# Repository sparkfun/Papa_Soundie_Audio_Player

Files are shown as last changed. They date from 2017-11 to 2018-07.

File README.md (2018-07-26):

SparkFun Papa Soundie Audio Player
========================================

Papa Soundie Audio Player

[*Papa Soundie Audio Player (14554)*](https://www.sparkfun.com/products/14554)

The SparkFun Papa Soundie is an audio playback device breaking out VS1000D audio codec IC allowing this little board the ability to decode OGG Vorbis and WAV type files. With an SD card for sound storage and a built-in ATmega328P programmed with Arduino you’ll be adding custom sound effects to your project with less hardware and in a familiar programming environment.

The Papa Soundie is the upgraded version of the Little Soundie with similar areas that allow you, the user, to interact with the board but with more customizable options. The top section of this board contains the Arduino Controls. We’ve broken out 2 analog input pins and 7 digital pins, which includes three PWM pins, SPI and I2C communication pins on the ATMEGA328P to easily control audio playback using sensors and other input.

Up to 32 files can be triggered to play from a micro SD card allowing for more storage space than that allowed on the Little Soundie. To play the audio stored in the SD card, plug in a powered speaker to the 3.5mm jack, upload an Arduino sketch the uses the Papa Soundie library, and start jammin'.

_Note: Speakers are required for the Papa Soundie, not headphones. Headphones won’t break anything but you won’t get any sound either._

Repository Contents
-------------------

* **/Documentation** - Data sheets, additional product information
* **/Enclosure** - Enclosure files 
* **/Firmware** - Example code 
* **/Hardware** - Eagle design files (.brd, .sch)
* **/Libraries** - Libraries for use with the Papa Soundie
* **/Production** - Production panel files (.brd)
* **/Software** - Related software for the Papa Soundie

Documentation
--------------
* **[Library](https://github.com/sparkfun/Papa_Soundie_Audio_Player)** - <C> library for the Papa Soundie.
* **[Hookup Guide](https://learn.sparkfun.com/tutorials/papa-soundie-audio-player-hookup-guide)** - Basic hookup guide for the Papa Soundie.
* **[SparkFun Fritzing repo](https://github.com/sparkfun/Fritzing_Parts)** - Fritzing diagrams for SparkFun products.
* **[SparkFun 3D Model repo](https://github.com/sparkfun/3D_Models)** - 3D models of SparkFun products. 
* **[SparkFun Graphical Datasheets](https://github.com/sparkfun/Graphical_Datasheets)** -Graphical Datasheets for various SparkFun products.

License Information
-------------------

This product is _**open source**_! 

Please review the LICENSE.md file for license information. 

If you have any questions or concerns on licensing, please contact techsupport@sparkfun.com.

Distributed as-is; no warranty is given.

- Your friends at SparkFun.

_<COLLABORATION CREDIT>_

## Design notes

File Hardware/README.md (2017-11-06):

SparkFun <PRODUCT NAME> Design Files
=====================================

The .sch and .brd files hare are Eagle CAD schematic and PCB design files from SparkFun Electronics.
A freeware version of Eagle can be found [here](http://www.cadsoftusa.com/download-eagle/freeware/).

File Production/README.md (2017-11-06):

SparkFun <PRODUCT NAME> Production Files
=========================================

These are the production files SparkFun uses for printing PCBs.

License Information
-------------------
This product is open source! 

The hardware is released under [Creative Commons ShareAlike 4.0 International](https://creativecommons.org/licenses/by-sa/4.0/).

Please use, reuse, and modify these files as you see fit. Please maintain attribution to SparkFun Electronics and release anything derivative under the same license.

Distributed as-is; no warranty is given.

- Your friends at SparkFun.

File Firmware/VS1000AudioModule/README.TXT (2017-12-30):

VS1000 Audio Module default firmware v0.72			20150720
-------------------------------------------------------------

Quickstart with VSIDE:
- Decompress the source code into your Solutions directory
- Start VSIDE and open VS1000AudioModule.solution
- Build all, and spiall.spi is created in the solution directory
  it is also copied to eeprom.img for easier programming
- Then program the module with the Prommer/Flasher utility
	"VS1000 SPI Flasher (24-bit) prepared image"
- If you don't have this version, you need to add the following entry to
  VSIDE\bin\prommer.index:

[vs1000_spi_flash_24bit_preparedimage]
Name                           = "VS1000 SPI Flasher (24-bit) prepared image"
TargetPlatform                 = "VS1000"
Description                    = "This VS1000 prommer can program SPI Flash memory chips with 24-bit address space. Communication is handled via UART cable. Image file has been prepared already by post-build step."
ImageName                      = "eeprom.img"
UseVs3Emu                      = "1"
PrommerBinary                  = "uniprom1k24.bin"
PrommerMemDesc                 = "prommer24.mem"

- One of the projects also create SDUPDATE.PRG for updates through SD card.
- Change settings from system.h (UART/GPIO, with or without WAV etc.)

Quickstart with Makefile:
- "make" (or "gmake") will compile and link the default firmware
- "make program" will program the default firmware to SPI FLASH
   if the FLASH already has a program, you must power on with SPI boot disabled

You can also use spi.bat to program the firmware:
> make spiall.spi prommer24.bin
> vs3emu -chip vs1000 -s 115200 -p 1 -l prommer24.bin -c run.cmd

Also see gpio-controlled player version.

Using SDUPDATE.PRG:
- SDUPDATE.PRG is a normal program, so it can do anything. The default
  SDUPDATE.PRG in the 0.4 version can update both the boot image
  (FIRMWARE.RAW) and the FAT disk content (CONTENT.RAW), depending on
  what files it finds on the SD card.
- Copy spiall.spi to FIRMWARE.RAW to update the firmware
- You can create CONTENT.RAW with for example the VS1000 image creator.
  Select SPI FLASH, no boot code, and set the Force FAT start to sector 0,
  so the resulting image will contain only the FAT.
- The SDUPDATE.PRG mechanism also exists in the 0.3 version,
  so you can update to 0.4 using uSD card.

Changes
=======
v0.72
- 20150720 with USE_POWERBUTTON, now requires the power button to be active
	for 0.2 sec before shutting down. (The 2FIN2 batch produces a
	pulse to PWRBTN when the uSD regulator is enabled.)

v0.70
- 20150113 The module datasheet updated.
- 20150107 USE_INFO includes 'i'nfo and 'I'nfo command to get the
	play length in seconds of a file without playing it. The same
	commands can be used to determine if a file exists.
- 20141117 USE_POWERBUTTON is now the default. You can turn off the module
	with a long press of the power button and turn the unit back on
	using the same button.
- 20141117 GAPLESS option added - selecting it from system.h will play files
	as back-to-back as possible. Only one-byte file number is printed when
	starting play and a single 'd' is sent when play ends (if UART mode).
- 20141117 A full version string with extra qualifiers such as
	-uart, -gpio, -queue, -filemode, -gapless is printed after startup.
- 20141115 Detects SPI FLASH size using the REMS sequence, so the size of
	the FLASH does not need to be correct when compiling the firmware.
	(If you want to reserve space for your own use, increase the
	 RESERVED_BLOCKS definition and use sectors from 64 upwards.)
- 20141113 Separated SD player and SD mass storage code. This frees up
	space so that more features can be used. The drawback is that uSD
	communication is reinitialized when switching between modes.
- 20141111 Fixed USE_MULTIPLE_BLOCK_WRITE in sdplayer.c . With it you
	can get around 500kB per second write speed to a modern uSD card.
	Note: This is not a default setting. You need to disable some other
	feature to fit it in (#undef USE_WAV in sdplayer.c or
	comment out //#define USE_WAV in system.h).
v0.65
- 20141028 Fixed 'P'lay by name when you have mixed OGG and WAV files.
	(Also gives file not found now if the file does not exist.)
v0.63
- 20140624 Added special button functions to gpioctrl.c .
   - prioritized buttons to select songs 1-3
   - STOP button
   - volume up and down buttons
   - power button is supported through USE_POWERBUTTON
v0.62
- 20140613 Added USE_POWERBUTTON to enable turn off using the PB input.
v0.61
- 20130923 Queueing option added. Enable both USE_QUEUE and DISABLE_USB
   from system.h to use it. DISABLE_USB removes the USB functionality from
   sdplayer.c, so that the queueing code can fit.
   When USE_QUEUE is active, the firmware starts in file mode. While in
   file mode and not playing, you can add files to the queue with
   "QFILENAMEOGG\n". If the file was found, the response will be
   "add FILENAME\n" or "ful\n" if there is no space in the queue,
   otherwise "nof FILENAME\n" (not found).
   Each queued file is added to the end of the queue.
   You can start playing the queue with "p0\n".
   In the play mode 'C' (cancel) only ends the play of the current file
   and continues with the next file in the queue. The same applies to
   'p' (previous) and 'n' (next) commands.

v0.60
- 20130118 MicroWav can now be enabled with USB (new libdev1000 required,
   included under lib/ with this VSIDE release).
	microwav does not support fast forward
0.51
- 20120621 Option to delete SDUPDATE.PRG from the SD card (see sdupdate.c)
- 20120621 Added a beep after programming is complete and you should remove the card.
 
0.5
- 20111209 VSIDE Solution of the UART version
- 20111209 mass storage functions changed. usbmass.c no longer
	provides audio + mass storage because win2000 and win7
	had some trouble with this kind of  composite device.
- 20111209 sdupdate.c: added a beep after programming is finished
- 20111025 sdplayer.c: removed GPIO_CONTROL stuff,
	added PatchPlayCurrentFile and PatchDiskProtocolCommandDE,
	fixes to uSD handling, MyMassStorage cleaned up.
	   spiplayer.c: removed GPIO_CONTROL stuff

0.4
- 20110429 QUIET_CANCEL define added (inactive) in uartctrl.c:
	when cancelled from pause state, lower volume so that
	portion of the old song will not be played.
- 20101223 Separated GPIO_CONTROL into its own package
- 20101213 Created GPIO_CONTROL version
- 20101115 Exec() crashed if not a valid FAT filesystem in SPI FLASH. (fixed)

0.31 20101115
- Changes to source package only. Makefile did not pass the MMCSTART
  define correctly in Linux and Windows.

0.3 20101027
- Added SD playback with UART control. The software now consists of
  three parts:
  1) usbmass, which is executed after power-on and handles USB Mass Storage
     for SPI FLASH, and loads spiplayer or sdplayer depeding on the SD/MMC
     insertion switch.
  2) spiplayer, which plays SPI FLASH content, loads sdplayer if SD/MMC
     insertion switch is triggered, and loads usbmass (using watchdog reset)
     if USB attachment is detected.
  3) sdplayer, which plays from SD/MMC, and also handles USB Mass Storage,
     and loads spiplayer if SD/MMC insertion switch is triggered.

0.2 20101011
- First version, UART control and playback from SPI FLASH.

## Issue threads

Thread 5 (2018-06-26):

Error in attempt to add library to Arduino 1.8.5.

restorey, 2018-06-26:
I cannot add Papa_Soundie_Audio_Player Library to Arduino IDE. When I try I get an error.
"Specified folder/zip file does not contain a valid library"

Arduino: 1.8.5 (Windows 10), Board: "Arduino Due (Programming Port)"

I am at a loss as to why this error pops up except there must be something wrong with the file.

per1234, 2018-06-26:
It's only possible to install libraries from a .zip file when the library is in the root of the file but in this case the library is in a subfolder so you can't use that installation technique with the .zip file of the entire repository.

SparkFun has added a .zip file of the library itself to the repository that you can use to install the library via the "Add .ZIP Library" technique:

1. Download https://github.com/sparkfun/Papa_Soundie_Audio_Player/raw/master/Libraries/Arduino/src.zip
2. (In the Arduino IDE) Sketch > Include Library > Add .ZIP Library > select the downloaded file > Open

restorey, 2018-06-26:
per1234. Thank you for the quick response. Download is now functional.
The problem stemmed from a link in the SparkFun tutorial for the Papa_Soundie_audio_player_hookup_guide.

Closed 2018-06-26.

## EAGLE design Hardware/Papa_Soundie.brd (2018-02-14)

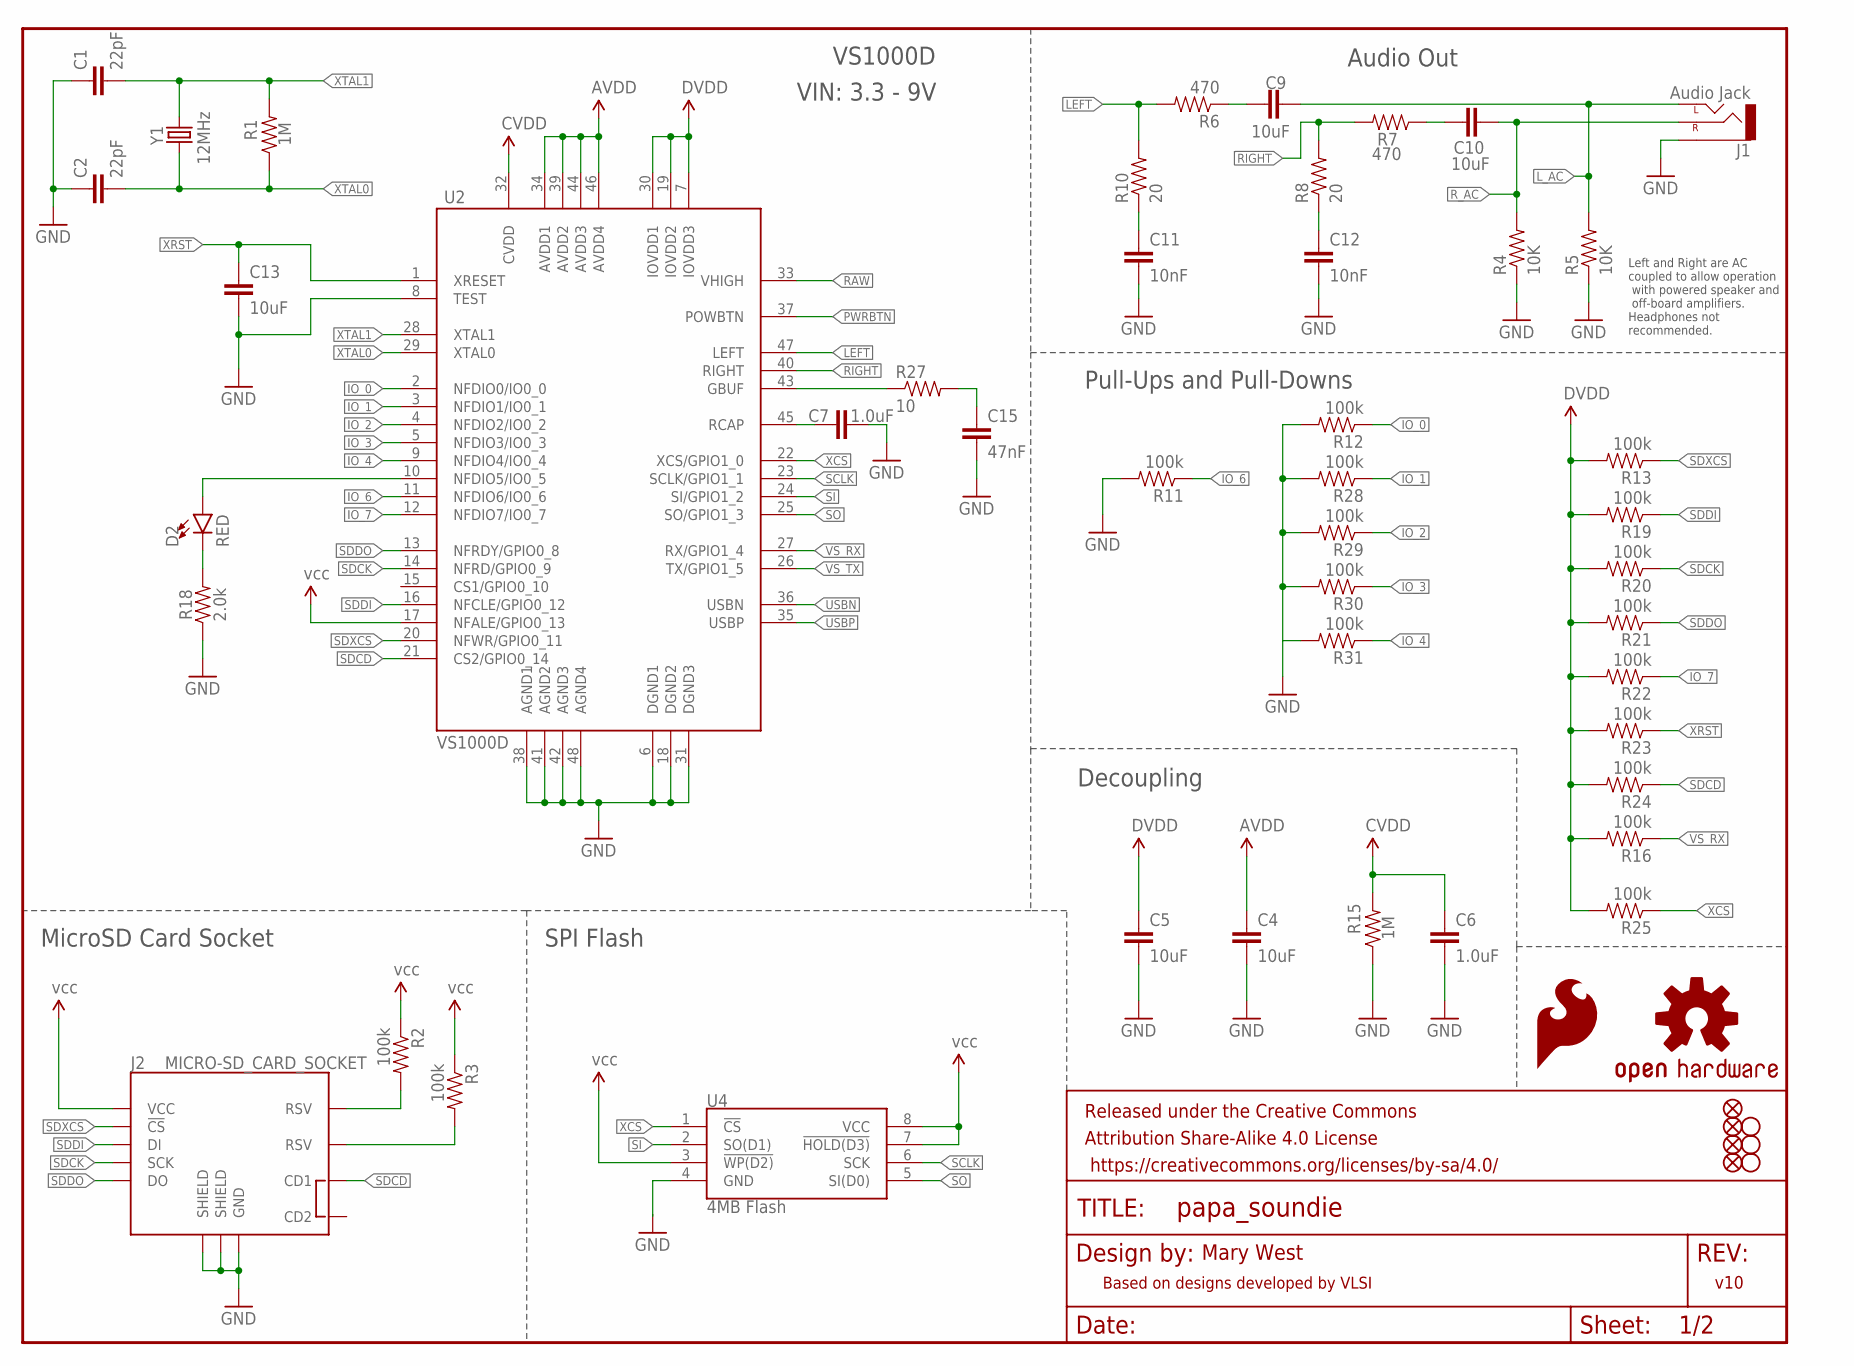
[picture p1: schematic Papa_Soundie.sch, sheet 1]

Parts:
C1, C2: 22pF; 0603-CAP
C4, C5: 10uF; 0603
C6, C7: 1.0uF; 0603-CAP
C9, C10, C13: 10uF; 0603-CAP
C11, C12: 10nF; 0603-CAP
C15: 47nF; 0603-CAP
D2: RED; LED-0603
FD1, FD2, FD3, FD4: FIDUCIALUFIDUCIAL; FIDUCIAL-MICRO
FRAME1: FRAME-LETTER; CREATIVE_COMMONS
H1, H2, H3: STAND-OFFTIGHT; STAND-OFF-TIGHT
J1: Audio Jack; AUDIO-JACK-3.5MM-SMD
J2: MICRO-SD_CARD_SOCKET; MICRO-SD-SOCKET
LOGO1: OSHW-LOGOL; OSHW-LOGO-L
LOGO2: SFE_LOGO_FLAME.2_INCH; SFE_LOGO_FLAME_.2
R1, R15: 1M; 0603-RES
R2, R3, R11, R12, R13, R16, R19, R20, R21, R22, R23, R24, R25, R28, R29, R30, R31: 100k; 0603-RES
R4, R5: 10K; 0603-RES
R6, R7: 470; 0603-RES
R8, R10: 20; 0603-RES
R18: 2.0k; 0603
R27: 10; 0603-RES
U2: VS1000D; LQFP-48
U4: 4MB Flash; SO08
Y1: 12MHz; CRYSTAL-SMD-5X3

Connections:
AVDD: C4.1, U2.34 (AVDD1), U2.39 (AVDD2), U2.44 (AVDD3), U2.46 (AVDD4)
CVDD: C6.1, R15.2, U2.32 (CVDD)
DVDD: C5.1, R13.2, R16.2, R19.2, R20.2, R21.2, R22.2, R23.2, R24.2, R25.2, U2.7 (IOVDD3), U2.19 (IOVDD2), U2.30 (IOVDD1)
GBUF: R27.1, U2.43 (GBUF)
GND: C1.1, C2.1, C4.2, C5.2, C6.2, C7.2, C11.2, C12.2, C13.2, C15.2, J1.SLEEVE, J2.GND, J2.GND1 (SHIELD), J2.GND3 (SHIELD), R4.1, R5.1, R11.2, R12.2, R15.1, R18.1, R28.2, R29.2, R30.2, R31.2, U2.6 (DGND1), U2.8 (TEST), U2.18 (DGND2), U2.31 (DGND3), U2.38 (AGND1), U2.41 (AGND2), U2.42 (AGND3), U2.48 (AGND4), U4.4 (GND); also elsewhere on the board
IO_0: R12.1, U2.2 (NFDIO0/IO0_0); also elsewhere on the board
IO_1: R28.1, U2.3 (NFDIO1/IO0_1); also elsewhere on the board
IO_2: R29.1, U2.4 (NFDIO2/IO0_2); also elsewhere on the board
IO_3: R30.1, U2.5 (NFDIO3/IO0_3); also elsewhere on the board
IO_4: R31.1, U2.9 (NFDIO4/IO0_4); also elsewhere on the board
IO_6: R11.1, U2.11 (NFDIO6/IO0_6)
IO_7: R22.1, U2.12 (NFDIO7/IO0_7)
LEFT: R6.2, R10.2, U2.47 (LEFT)
L_AC: C9.2, J1.TIP (LEFT), R5.2; also elsewhere on the board
unnamed: C15.1, R27.2
unnamed: C9.1, R6.1
unnamed: C11.1, R10.1
unnamed: C7.1, U2.45 (RCAP)
unnamed: J2.RSV1 (RSV), R2.2
unnamed: C10.1, R7.1
unnamed: J2.RSV2 (RSV), R3.2
unnamed: C12.1, R8.1
unnamed: D2.C, R18.2
unnamed: D2.A, U2.10 (NFDIO5/IO0_5)
PWRBTN: U2.37 (POWBTN); also elsewhere on the board
RAW: U2.33 (VHIGH); also elsewhere on the board
RIGHT: R7.2, R8.2, U2.40 (RIGHT)
R_AC: C10.2, J1.RING (RIGHT), R4.2; also elsewhere on the board
SCLK: U2.23 (SCLK/GPIO1_1), U4.6 (SCK)
SDCD: J2.CD1, R24.1, U2.21 (CS2/GPIO0_14)
SDCK: J2.SCLK (SCK), R20.1, U2.14 (NFRD/GPIO0_9)
SDDI: J2.DI, R19.1, U2.16 (NFCLE/GPIO0_12)
SDDO: J2.DO, R21.1, U2.13 (NFRDY/GPIO0_8)
SDXCS: J2.CS (!CS), R13.1, U2.20 (NFWR/GPIO0_11)
SI: U2.24 (SI/GPIO1_2), U4.2 (SO(D1))
SO: U2.25 (SO/GPIO1_3), U4.5 (SI(D0))
USBN: U2.36 (USBN); also elsewhere on the board
USBP: U2.35 (USBP); also elsewhere on the board
VCC: J2.VCC, R2.1, R3.1, U2.17 (NFALE/GPIO0_13), U4.3 (!WP(D2)), U4.7 (!HOLD(D3)), U4.8 (VCC); also elsewhere on the board
VS_RX: R16.1, U2.27 (RX/GPIO1_4); also elsewhere on the board
VS_TX: U2.26 (TX/GPIO1_5); also elsewhere on the board
XCS: R25.1, U2.22 (XCS/GPIO1_0), U4.1 (!CS)
XRST: C13.1, R23.1, U2.1 (XRESET)
XTAL0: C2.2, R1.1, U2.29 (XTAL0), Y1.1
XTAL1: C1.2, R1.2, U2.28 (XTAL1), Y1.3 (2)

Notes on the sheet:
Mary West
v10
Decoupling
Left and Right are AC coupled to allow operation with powered speaker and off-board amplifiers. Headphones not recommended.
Based on designs developed by VLSI
Audio Out
MicroSD Card Socket
Pull-Ups and Pull-Downs
SPI Flash
VS1000D
VIN: 3.3 - 9V

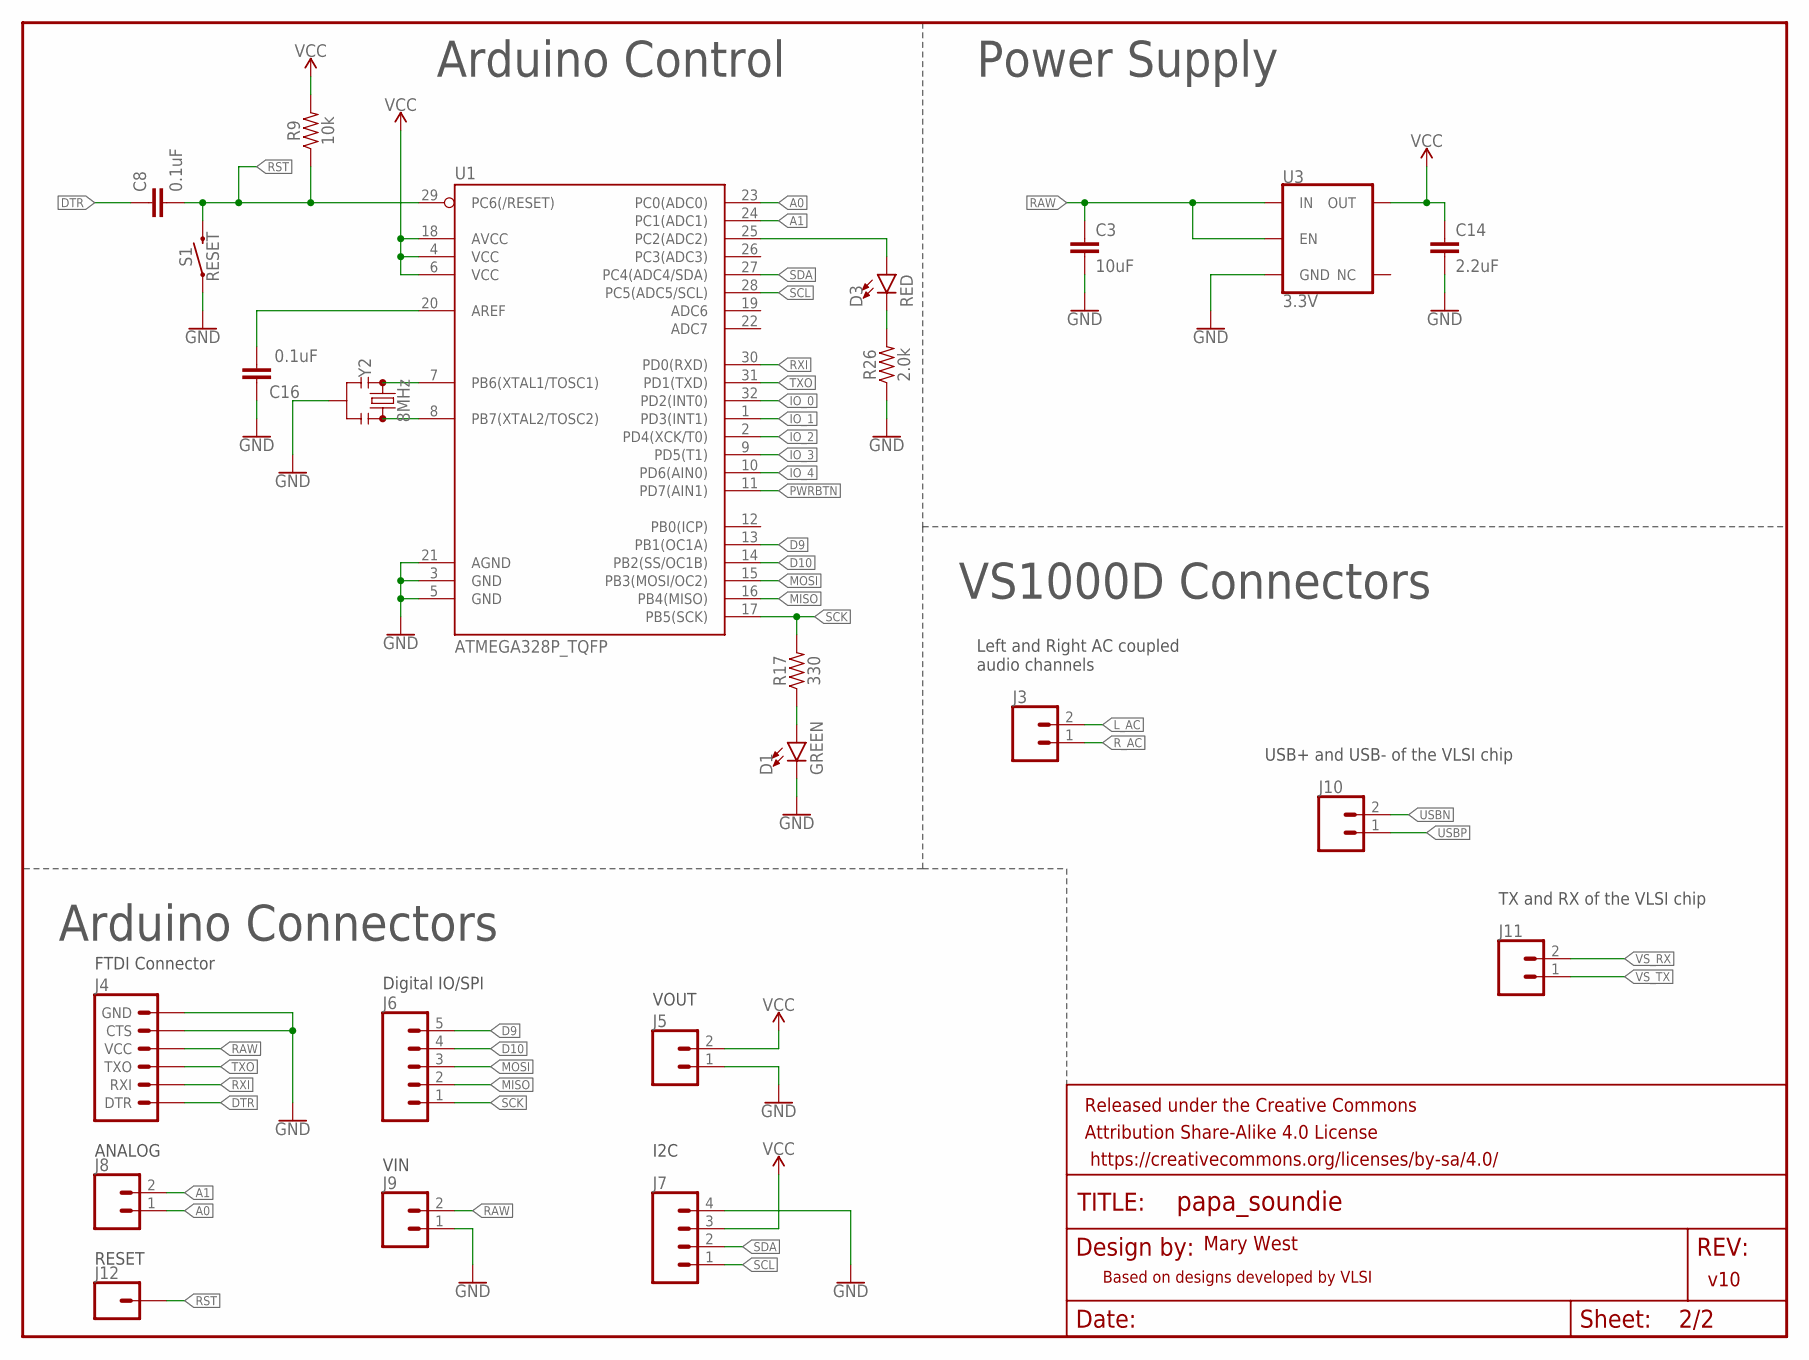
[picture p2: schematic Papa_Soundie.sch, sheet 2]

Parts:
C3: 10uF; 0603
C8, C16: 0.1uF; 0603
C14: 2.2uF; 0603
D1: GREEN; LED-0603
D3: RED; LED-0603
FRAME2: FRAME-LETTER; CREATIVE_COMMONS
J3, J5, J8, J9, J10, J11: CONN_02; 1X02
J4: 6_PIN_SERIAL_TARGETSILK; 6_PIN_SERIAL_TARGET_SIDE_W_SILK
J6: CONN_05; 1X05
J7: CONN_04; 1X04
J12: CONN_01; 1X01
R9: 10k; 0603
R17: 330; 0603
R26: 2.0k; 0603
S1: RESET; TACTILE_SWITCH_SMD_5.2MM
U1: ATMEGA328P_TQFP; TQFP32-08
U3: 3.3V; SOT23-5
Y2: 8MHz; RESONATOR-SMD-3.2X1.3

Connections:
A0: J8.1, U1.23 (PC0(ADC0))
A1: J8.2, U1.24 (PC1(ADC1))
D9: J6.5, U1.13 (PB1(OC1A))
D10: J6.4, U1.14 (PB2(SS/OC1B))
DTR: C8.1, J4.P$1 (DTR)
GND: C3.2, C14.2, C16.1, D1.C, J4.P$5 (CTS), J4.P$6 (GND), J5.1, J7.4, J9.1, R26.1, S1.1, U1.3 (GND), U1.5 (GND), U1.21 (AGND), U3.2 (GND), Y2.2; also elsewhere on the board
IO_0: U1.32 (PD2(INT0)); also elsewhere on the board
IO_1: U1.1 (PD3(INT1)); also elsewhere on the board
IO_2: U1.2 (PD4(XCK/T0)); also elsewhere on the board
IO_3: U1.9 (PD5(T1)); also elsewhere on the board
IO_4: U1.10 (PD6(AIN0)); also elsewhere on the board
L_AC: J3.2; also elsewhere on the board
MISO: J6.2, U1.16 (PB4(MISO))
MOSI: J6.3, U1.15 (PB3(MOSI/OC2))
unnamed: U1.7 (PB6(XTAL1/TOSC1)), Y2.1
unnamed: U1.8 (PB7(XTAL2/TOSC2)), Y2.3
unnamed: D3.A, U1.25 (PC2(ADC2))
unnamed: D3.C, R26.2
unnamed: C16.2, U1.20 (AREF)
unnamed: D1.A, R17.1
PWRBTN: U1.11 (PD7(AIN1)); also elsewhere on the board
RAW: C3.1, J4.P$4 (VCC), J9.2, U3.1 (IN), U3.3 (EN); also elsewhere on the board
RST: C8.2, J12.1, R9.1, S1.3 (2), U1.29 (PC6(/RESET))
RXI: J4.P$3 (RXI), U1.30 (PD0(RXD))
R_AC: J3.1; also elsewhere on the board
SCK: J6.1, R17.2, U1.17 (PB5(SCK))
SCL: J7.1, U1.28 (PC5(ADC5/SCL))
SDA: J7.2, U1.27 (PC4(ADC4/SDA))
TXO: J4.P$2 (TXO), U1.31 (PD1(TXD))
USBN: J10.2; also elsewhere on the board
USBP: J10.1; also elsewhere on the board
VCC: C14.1, J5.2, J7.3, R9.2, U1.4 (VCC), U1.6 (VCC), U1.18 (AVCC), U3.5 (OUT); also elsewhere on the board
VS_RX: J11.2; also elsewhere on the board
VS_TX: J11.1; also elsewhere on the board

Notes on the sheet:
Arduino Control
Mary West
v10
Power Supply
VS1000D Connectors
Arduino Connectors
Left and Right AC coupled audio channels
USB+ and USB- of the VLSI chip
TX and RX of the VLSI chip
VOUT
I2C
Digital IO/SPI
FTDI Connector
ANALOG
VIN
RESET
Based on designs developed by VLSI

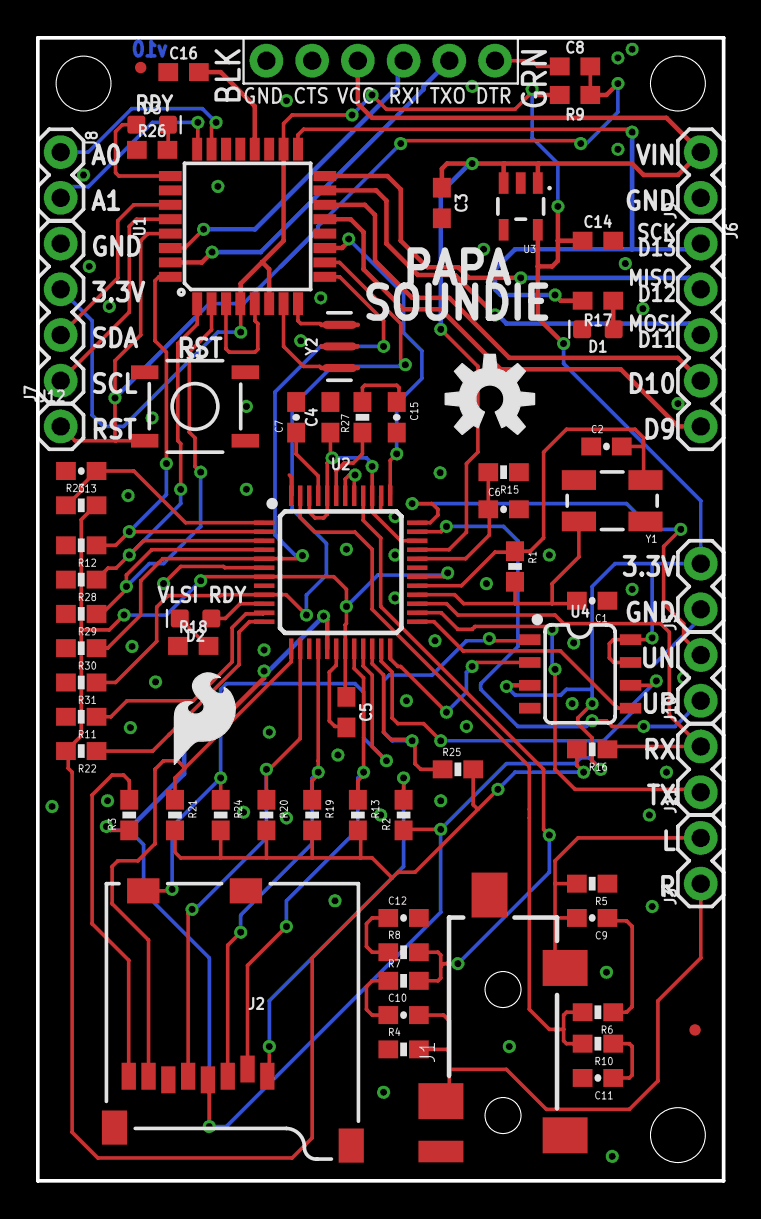
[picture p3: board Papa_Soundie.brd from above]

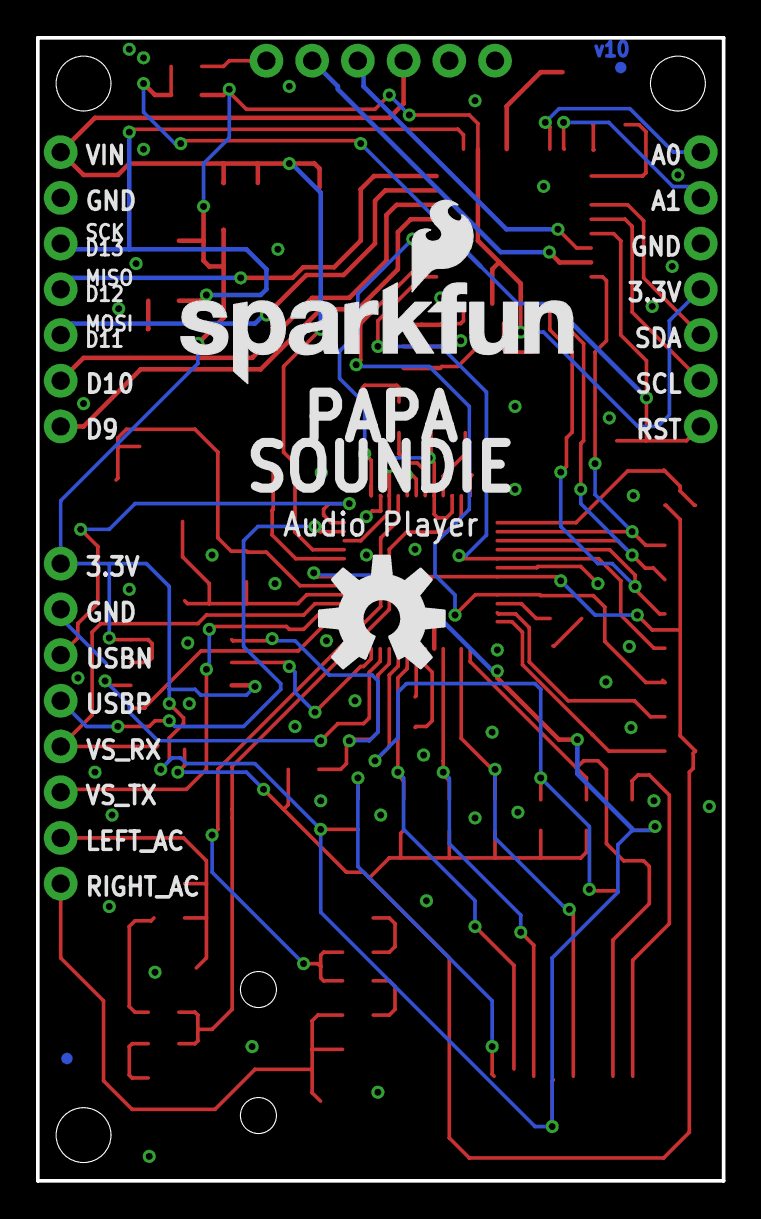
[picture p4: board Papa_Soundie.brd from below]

Board: 2 copper layers, 38.1 x 63.5 mm, 82 parts (4 on the bottom side), 64 nets.

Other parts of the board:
FRAME3: FRAME-LETTER; CREATIVE_COMMONS
LOGO3: OSHW-LOGOL; OSHW-LOGO-M
LOGO6: SFE_LOGO_NAME_FLAME.1_INCH; SFE_LOGO_NAME_FLAME_.2

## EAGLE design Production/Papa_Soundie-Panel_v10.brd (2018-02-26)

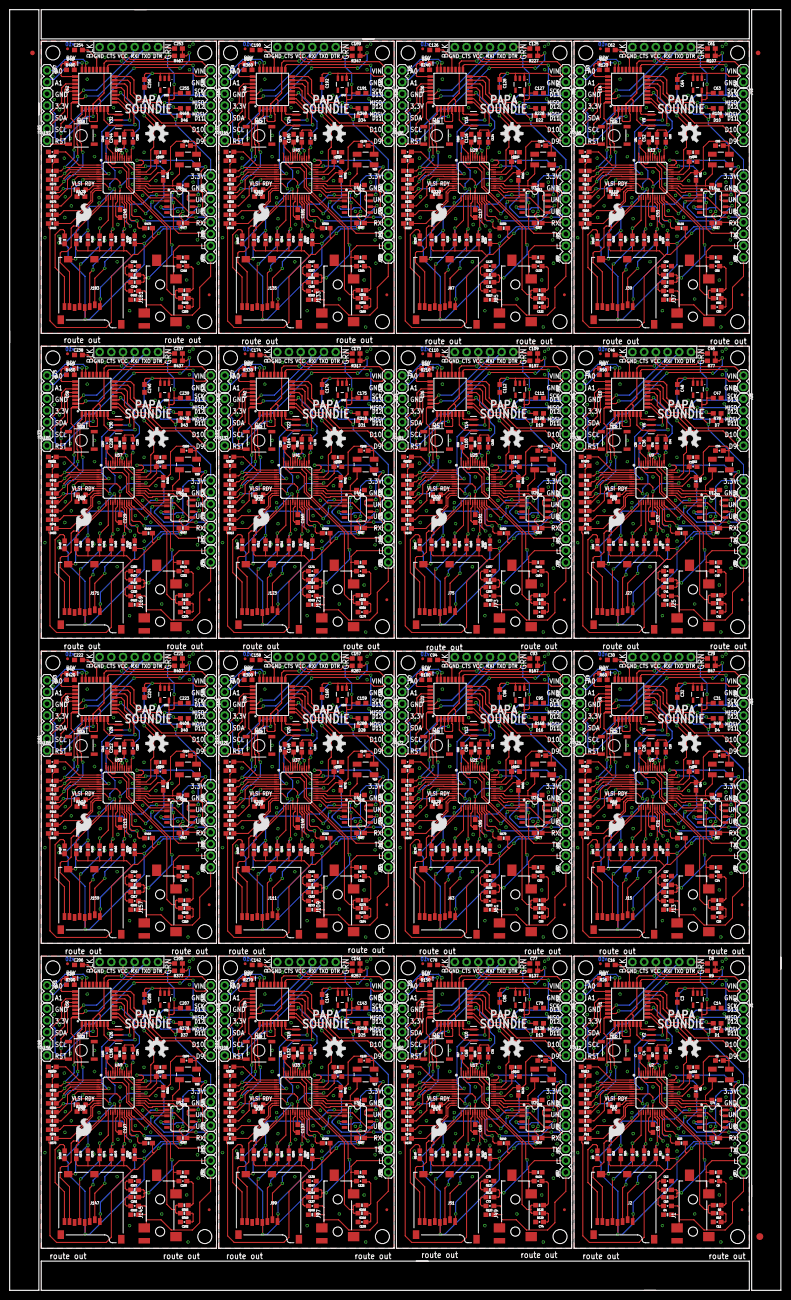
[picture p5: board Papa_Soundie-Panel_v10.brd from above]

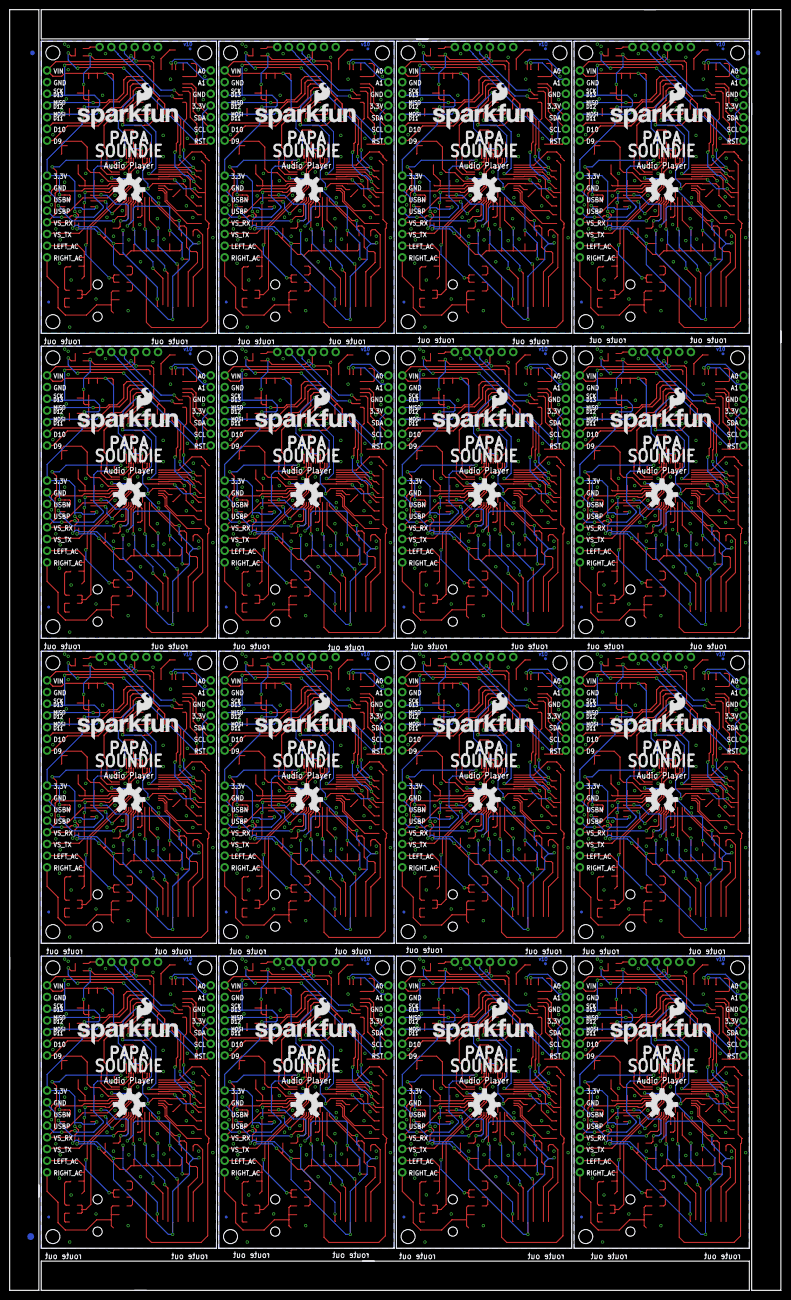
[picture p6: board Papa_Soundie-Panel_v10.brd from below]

Board: 2 copper layers, 167.6 x 278.4 mm, 1270 parts (67 on the bottom side), 1024 nets.

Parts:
C1, C2, C17, C18, C33, C34, C49, C50, C65, C66, C81, C82, C97, C98, C113, C114, C129, C130, C145, C146, C161, C162, C177, C178, C193, C194, C209, C210, C225, C226, C241, C242: 22pF; 0603-CAP
C3, C4, C5, C20, C21, C32, C36, C37, C48, C52, C53, C64, C68, C69, C80, C84, C85, C96, C100, C101, C112, C116, C117, C128, C132, C133, C144, C148, C149, C160, C164, C165, C176, C180, C181, C192, C196, C197, C208, C212, C213, C224, C228, C229, C240, C244, C245, C256: 10uF; 0603
C6, C7, C19, C22, C35, C38, C51, C54, C67, C70, C83, C86, C99, C102, C115, C118, C131, C134, C147, C150, C163, C166, C179, C182, C195, C198, C211, C214, C227, C230, C243, C246: 1.0uF; 0603-CAP
C8, C16, C29, C30, C45, C46, C61, C62, C77, C78, C93, C94, C109, C110, C125, C126, C141, C142, C157, C158, C173, C174, C189, C190, C205, C206, C221, C222, C237, C238, C253, C254: 0.1uF; 0603
C9, C10, C13, C23, C24, C25, C39, C40, C41, C55, C56, C57, C71, C72, C73, C87, C88, C89, C103, C104, C105, C119, C120, C121, C135, C136, C137, C151, C152, C153, C167, C168, C169, C183, C184, C185, C199, C200, C201, C215, C216, C217, C231, C232, C233, C247, C248, C249: 10uF; 0603-CAP
C11, C12, C26, C27, C42, C43, C58, C59, C74, C75, C90, C91, C106, C107, C122, C123, C138, C139, C154, C155, C170, C171, C186, C187, C202, C203, C218, C219, C234, C235, C250, C251: 10nF; 0603-CAP
C14, C31, C47, C63, C79, C95, C111, C127, C143, C159, C175, C191, C207, C223, C239, C255: 2.2uF; 0603
C15, C28, C44, C60, C76, C92, C108, C124, C140, C156, C172, C188, C204, C220, C236, C252: 47nF; 0603-CAP
D1, D4, D7, D10, D13, D16, D19, D22, D25, D28, D31, D34, D37, D40, D43, D46: GREEN; LED-0603
D2, D3, D5, D6, D8, D9, D11, D12, D14, D15, D17, D18, D20, D21, D23, D24, D26, D27, D29, D30, D32, D33, D35, D36, D38, D39, D41, D42, D44, D45, D47, D48: RED; LED-0603
E$1, E$2: FIDUCIAL-1.5X3
E$3, E$4, E$6, E$7: FIDUCIAL-1X2
FD1, FD2, FD3, FD4, FD5, FD6, FD7, FD8, FD9, FD10, FD11, FD12, FD13, FD14, FD15, FD16, FD17, FD18, FD19, FD20, FD21, FD22, FD23, FD24, FD25, FD26, FD27, FD28, FD29, FD30, FD31, FD32, FD33, FD34, FD35, FD36, FD37, FD38, FD39, FD40, FD41, FD42, FD43, FD44, FD45, FD46, FD47, FD48, FD49, FD50, FD51, FD52, FD53, FD54, FD55, FD56, FD57, FD58, FD59, FD60, FD61, FD62, FD63, FD64: FIDUCIALUFIDUCIAL; FIDUCIAL-MICRO
H1, H2, H3, H4, H5, H6, H7, H8, H9, H10, H11, H12, H13, H14, H15, H16, H17, H18, H19, H20, H21, H22, H23, H24, H25, H26, H27, H28, H29, H30, H31, H32, H33, H34, H35, H36, H37, H38, H39, H40, H41, H42, H43, H44, H45, H46, H47, H48: STAND-OFFTIGHT; STAND-OFF-TIGHT
J1, J13, J25, J37, J49, J61, J73, J85, J97, J109, J121, J133, J145, J157, J169, J181: Audio Jack; AUDIO-JACK-3.5MM-SMD
J2, J15, J27, J39, J51, J63, J75, J87, J99, J111, J123, J135, J147, J159, J171, J183: MICRO-SD_CARD_SOCKET; MICRO-SD-SOCKET
J3, J5, J8, J9, J10, J11, J18, J19, J20, J21, J22, J23, J30, J31, J32, J33, J34, J35, J42, J43, J44, J45, J46, J47, J54, J55, J56, J57, J58, J59, J66, J67, J68, J69, J70, J71, J78, J79, J80, J81, J82, J83, J90, J91, J92, J93, J94, J95, J102, J103, J104, J105, J106, J107, J114, J115, J116, J117, J118, J119, J126, J127, J128, J129, J130, J131, J138, J139, J140, J141, J142, J143, J150, J151, J152, J153, J154, J155, J162, J163, J164, J165, J166, J167, J174, J175, J176, J177, J178, J179, J186, J187, J188, J189, J190, J191: 1X02
J4, J14, J26, J38, J50, J62, J74, J86, J98, J110, J122, J134, J146, J158, J170, J182: 6_PIN_SERIAL_TARGET_SIDE_W_SILK
J6, J16, J28, J40, J52, J64, J76, J88, J100, J112, J124, J136, J148, J160, J172, J184: 1X05
J7, J17, J29, J41, J53, J65, J77, J89, J101, J113, J125, J137, J149, J161, J173, J185: 1X04
J12, J24, J36, J48, J60, J72, J84, J96, J108, J120, J132, J144, J156, J168, J180, J192: 1X01
LOGO1, LOGO4, LOGO9, LOGO13, LOGO17, LOGO21, LOGO25, LOGO29, LOGO33, LOGO37, LOGO41, LOGO45, LOGO49, LOGO53, LOGO57, LOGO61: OSHW-LOGOL; OSHW-LOGO-L
LOGO2, LOGO5, LOGO10, LOGO14, LOGO18, LOGO22, LOGO26, LOGO30, LOGO34, LOGO38, LOGO42, LOGO46, LOGO50, LOGO54, LOGO58, LOGO62: SFE_LOGO_FLAME.2_INCH; SFE_LOGO_FLAME_.2
LOGO3, LOGO8, LOGO12, LOGO16, LOGO20, LOGO24, LOGO28, LOGO32, LOGO36, LOGO40, LOGO44, LOGO48, LOGO52, LOGO56, LOGO60, LOGO64: OSHW-LOGOL; OSHW-LOGO-M
LOGO6, LOGO7, LOGO11, LOGO15, LOGO19, LOGO23, LOGO27, LOGO31, LOGO35, LOGO39, LOGO43, LOGO47, LOGO51, LOGO55, LOGO59, LOGO63: SFE_LOGO_NAME_FLAME.1_INCH; SFE_LOGO_NAME_FLAME_.2
R1, R14, R15, R32, R61, R62, R91, R92, R121, R122, R151, R152, R181, R182, R211, R212, R241, R242, R271, R272, R301, R302, R331, R332, R361, R362, R391, R392, R421, R422, R451, R452: 1M; 0603-RES
R2, R3, R11, R12, R13, R16, R19, R20, R21, R22, R23, R24, R25, R28, R29, R30, R31, R39, R40, R41, R42, R43, R44, R45, R49, R50, R51, R52, R53, R54, R55, R56, R57, R58, R69, R70, R71, R72, R73, R74, R75, R79, R80, R81, R82, R83, R84, R85, R86, R87, R88, R99, R100, R101, R102, R103, R104, R105, R109, R110, R111, R112, R113, R114, R115, R116, R117, R118, R129, R130, R131, R132, R133, R134, R135, R139, R140, R141, R142, R143, R144, R145, R146, R147, R148, R159, R160, R161, R162, R163, R164, R165, R169, R170, R171, R172, R173, R174, R175, R176, R177, R178, R189, R190, R191, R192, R193, R194, R195, R199, R200, R201, R202, R203, R204, R205, R206, R207, R208, R219, R220, R221, R222, R223, R224, R225, R229, R230, R231, R232, R233, R234, R235, R236, R237, R238, R249, R250, R251, R252, R253, R254, R255, R259, R260, R261, R262, R263, R264, R265, R266, R267, R268, R279, R280, R281, R282, R283, R284, R285, R289, R290, R291, R292, R293, R294, R295, R296, R297, R298, R309, R310, R311, R312, R313, R314, R315, R319, R320, R321, R322, R323, R324, R325, R326, R327, R328, R339, R340, R341, R342, R343, R344, R345, R349, R350, R351, R352, R353, R354, R355, R356, R357, R358, R369, R370, R371, R372, R373, R374, R375, R379, R380, R381, R382, R383, R384, R385, R386, R387, R388, R399, R400, R401, R402, R403, R404, R405, R409, R410, R411, R412, R413, R414, R415, R416, R417, R418, R429, R430, R431, R432, R433, R434, R435, R439, R440, R441, R442, R443, R444, R445, R446, R447, R448, R459, R460, R461, R462, R463, R464, R465, R469, R470, R471, R472, R473, R474, R475, R476, R477, R478: 100k; 0603-RES
R4, R5, R33, R34, R63, R64, R93, R94, R123, R124, R153, R154, R183, R184, R213, R214, R243, R244, R273, R274, R303, R304, R333, R334, R363, R364, R393, R394, R423, R424, R453, R454: 10K; 0603-RES
R6, R7, R35, R36, R65, R66, R95, R96, R125, R126, R155, R156, R185, R186, R215, R216, R245, R246, R275, R276, R305, R306, R335, R336, R365, R366, R395, R396, R425, R426, R455, R456: 470; 0603-RES
R8, R10, R37, R38, R67, R68, R97, R98, R127, R128, R157, R158, R187, R188, R217, R218, R247, R248, R277, R278, R307, R308, R337, R338, R367, R368, R397, R398, R427, R428, R457, R458: 20; 0603-RES
R9, R47, R77, R107, R137, R167, R197, R227, R257, R287, R317, R347, R377, R407, R437, R467: 10k; 0603
R17, R48, R78, R108, R138, R168, R198, R228, R258, R288, R318, R348, R378, R408, R438, R468: 330; 0603
R18, R26, R59, R60, R89, R90, R119, R120, R149, R150, R179, R180, R209, R210, R239, R240, R269, R270, R299, R300, R329, R330, R359, R360, R389, R390, R419, R420, R449, R450, R479, R480: 2.0k; 0603
R27, R46, R76, R106, R136, R166, R196, R226, R256, R286, R316, R346, R376, R406, R436, R466: 10; 0603-RES
S1, S2, S3, S4, S5, S6, S7, S8, S9, S10, S11, S12, S13, S14, S15, S16: RESET; TACTILE_SWITCH_SMD_5.2MM
U1, U6, U10, U14, U18, U22, U26, U30, U34, U38, U42, U46, U50, U54, U58, U62: ATMEGA328P_TQFP; TQFP32-08
U2, U5, U9, U13, U17, U21, U25, U29, U33, U37, U41, U45, U49, U53, U57, U61: VS1000D; LQFP-48
U3, U7, U11, U15, U19, U23, U27, U31, U35, U39, U43, U47, U51, U55, U59, U63: 3.3V; SOT23-5
U4, U8, U12, U16, U20, U24, U28, U32, U36, U40, U44, U48, U52, U56, U60, U64: 4MB Flash; SO08
Y1, Y3, Y5, Y7, Y9, Y11, Y13, Y15, Y17, Y19, Y21, Y23, Y25, Y27, Y29, Y31: 12MHz; CRYSTAL-SMD-5X3
Y2, Y4, Y6, Y8, Y10, Y12, Y14, Y16, Y18, Y20, Y22, Y24, Y26, Y28, Y30, Y32: 8MHz; RESONATOR-SMD-3.2X1.3

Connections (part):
A0: J8.1, U1.23
A1: J8.2, U1.24
A2: J19.1, U6.23
A3: J19.2, U6.24
A4: J31.1, U10.23
A5: J31.2, U10.24
A6: J43.1, U14.23
A7: J43.2, U14.24
A8: J55.1, U18.23
A9: J55.2, U18.24
A10: J67.1, U22.23
A11: J67.2, U22.24
A12: J79.1, U26.23
A13: J79.2, U26.24
A14: J91.1, U30.23
A15: J91.2, U30.24
A16: J103.1, U34.23
A17: J103.2, U34.24
A18: J115.1, U38.23
A19: J115.2, U38.24
A20: J127.1, U42.23
A21: J127.2, U42.24
A22: J139.1, U46.23
A23: J139.2, U46.24
A24: J151.1, U50.23
A25: J151.2, U50.24
A26: J163.1, U54.23
A27: J163.2, U54.24
A28: J175.1, U58.23
A29: J175.2, U58.24
A30: J187.1, U62.23
A31: J187.2, U62.24
AVDD: C4.1, U2.34, U2.39, U2.44, U2.46
AVDD1: C20.1, U5.34, U5.39, U5.44, U5.46
AVDD2: C36.1, U9.34, U9.39, U9.44, U9.46
AVDD3: C52.1, U13.34, U13.39, U13.44, U13.46
AVDD4: C68.1, U17.34, U17.39, U17.44, U17.46
AVDD5: C84.1, U21.34, U21.39, U21.44, U21.46
AVDD6: C100.1, U25.34, U25.39, U25.44, U25.46
AVDD7: C116.1, U29.34, U29.39, U29.44, U29.46
AVDD8: C132.1, U33.34, U33.39, U33.44, U33.46
AVDD9: C148.1, U37.34, U37.39, U37.44, U37.46
AVDD10: C164.1, U41.34, U41.39, U41.44, U41.46
AVDD11: C180.1, U45.34, U45.39, U45.44, U45.46
AVDD12: C196.1, U49.34, U49.39, U49.44, U49.46
AVDD13: C212.1, U53.34, U53.39, U53.44, U53.46
AVDD14: C228.1, U57.34, U57.39, U57.44, U57.46
AVDD15: C244.1, U61.34, U61.39, U61.44, U61.46
CVDD: C6.1, R15.2, U2.32
CVDD1: C22.1, R32.2, U5.32
CVDD2: C38.1, R62.2, U9.32
CVDD3: C54.1, R92.2, U13.32
CVDD4: C70.1, R122.2, U17.32
CVDD5: C86.1, R152.2, U21.32
CVDD6: C102.1, R182.2, U25.32
CVDD7: C118.1, R212.2, U29.32
CVDD8: C134.1, R242.2, U33.32
CVDD9: C150.1, R272.2, U37.32
CVDD10: C166.1, R302.2, U41.32
CVDD11: C182.1, R332.2, U45.32
CVDD12: C198.1, R362.2, U49.32
CVDD13: C214.1, R392.2, U53.32
CVDD14: C230.1, R422.2, U57.32
CVDD15: C246.1, R452.2, U61.32
D1: J16.5, U6.13
D2: J16.4, U6.14
D3: J28.5, U10.13
D4: J28.4, U10.14
D5: J40.5, U14.13
D6: J40.4, U14.14
D7: J52.5, U18.13
D8: J52.4, U18.14
D9: J6.5, U1.13
D10: J6.4, U1.14
D11: J64.5, U22.13
D12: J64.4, U22.14
D13: J76.5, U26.13
D14: J76.4, U26.14
D15: J88.5, U30.13
D16: J88.4, U30.14
D17: J100.5, U34.13
D18: J100.4, U34.14
D19: J112.5, U38.13
D20: J112.4, U38.14
D21: J124.5, U42.13
D22: J124.4, U42.14
D23: J136.5, U46.13
D24: J136.4, U46.14
D25: J148.5, U50.13
D26: J148.4, U50.14
D27: J160.5, U54.13
D28: J160.4, U54.14
D29: J172.5, U58.13
D30: J172.4, U58.14
D31: J184.5, U62.13
D32: J184.4, U62.14
DTR: C8.1, J4.P$1
DTR1: C29.1, J14.P$1
DTR2: C45.1, J26.P$1
DTR3: C61.1, J38.P$1
DTR4: C77.1, J50.P$1
DTR5: C93.1, J62.P$1
DTR6: C109.1, J74.P$1
DTR7: C125.1, J86.P$1
DTR8: C141.1, J98.P$1
DTR9: C157.1, J110.P$1
DTR10: C173.1, J122.P$1
DTR11: C189.1, J134.P$1
DTR12: C205.1, J146.P$1
DTR13: C221.1, J158.P$1
DTR14: C237.1, J170.P$1
DTR15: C253.1, J182.P$1
DVDD: C5.1, R13.2, R16.2, R19.2, R20.2, R21.2, R22.2, R23.2, R24.2, R25.2, U2.7, U2.19, U2.30
DVDD1: C21.1, R39.2, R40.2, R41.2, R42.2, R43.2, R44.2, R45.2, R57.2, R58.2, U5.7, U5.19, U5.30
DVDD2: C37.1, R69.2, R70.2, R71.2, R72.2, R73.2, R74.2, R75.2, R87.2, R88.2, U9.7, U9.19, U9.30
DVDD3: C53.1, R99.2, R100.2, R101.2, R102.2, R103.2, R104.2, R105.2, R117.2, R118.2, U13.7, U13.19, U13.30
DVDD4: C69.1, R129.2, R130.2, R131.2, R132.2, R133.2, R134.2, R135.2, R147.2, R148.2, U17.7, U17.19, U17.30
DVDD5: C85.1, R159.2, R160.2, R161.2, R162.2, R163.2, R164.2, R165.2, R177.2, R178.2, U21.7, U21.19, U21.30
DVDD6: C101.1, R189.2, R190.2, R191.2, R192.2, R193.2, R194.2, R195.2, R207.2, R208.2, U25.7, U25.19, U25.30
DVDD7: C117.1, R219.2, R220.2, R221.2, R222.2, R223.2, R224.2, R225.2, R237.2, R238.2, U29.7, U29.19, U29.30
DVDD8: C133.1, R249.2, R250.2, R251.2, R252.2, R253.2, R254.2, R255.2, R267.2, R268.2, U33.7, U33.19, U33.30
DVDD9: C149.1, R279.2, R280.2, R281.2, R282.2, R283.2, R284.2, R285.2, R297.2, R298.2, U37.7, U37.19, U37.30
DVDD10: C165.1, R309.2, R310.2, R311.2, R312.2, R313.2, R314.2, R315.2, R327.2, R328.2, U41.7, U41.19, U41.30
DVDD11: C181.1, R339.2, R340.2, R341.2, R342.2, R343.2, R344.2, R345.2, R357.2, R358.2, U45.7, U45.19, U45.30
DVDD12: C197.1, R369.2, R370.2, R371.2, R372.2, R373.2, R374.2, R375.2, R387.2, R388.2, U49.7, U49.19, U49.30
DVDD13: C213.1, R399.2, R400.2, R401.2, R402.2, R403.2, R404.2, R405.2, R417.2, R418.2, U53.7, U53.19, U53.30
DVDD14: C229.1, R429.2, R430.2, R431.2, R432.2, R433.2, R434.2, R435.2, R447.2, R448.2, U57.7, U57.19, U57.30
DVDD15: C245.1, R459.2, R460.2, R461.2, R462.2, R463.2, R464.2, R465.2, R477.2, R478.2, U61.7, U61.19, U61.30
GBUF: R27.1, U2.43
GBUF1: R46.1, U5.43
GBUF2: R76.1, U9.43
GBUF3: R106.1, U13.43
GBUF4: R136.1, U17.43
GBUF5: R166.1, U21.43
GBUF6: R196.1, U25.43
GBUF7: R226.1, U29.43
GBUF8: R256.1, U33.43
GBUF9: R286.1, U37.43
GBUF10: R316.1, U41.43
GBUF11: R346.1, U45.43
GBUF12: R376.1, U49.43
GBUF13: R406.1, U53.43
GBUF14: R436.1, U57.43
GBUF15: R466.1, U61.43
GND: C1.1, C2.1, C3.2, C4.2, C5.2, C6.2, C7.2, C11.2, C12.2, C13.2, C14.2, C15.2, C16.1, D1.C, J1.SLEEVE, J2.GND, J2.GND1, J2.GND3, J4.P$5, J4.P$6, J5.1, J7.4, J9.1, R4.1, R5.1, R11.2, R12.2, R15.1, R18.1, R26.1, R28.2, R29.2, R30.2, R31.2, S1.1, U1.3, U1.5, U1.21, U2.6, U2.8, U2.18, U2.31, U2.38, U2.41, U2.42, U2.48, U3.2, U4.4, Y2.2
GND1: C17.1, C18.1, C19.2, C20.2, C21.2, C22.2, C23.2, C26.2, C27.2, C28.2, C30.1, C31.2, C32.2, D4.C, J13.SLEEVE, J14.P$5, J14.P$6, J15.GND, J15.GND1, J15.GND3, J17.4, J20.1, J22.1, R32.1, R33.1, R34.1, R51.2, R52.2, R53.2, R54.2, R55.2, R56.2, R59.1, R60.1, S2.1, U5.6, U5.8, U5.18, U5.31, U5.38, U5.41, U5.42, U5.48, U6.3, U6.5, U6.21, U7.2, U8.4, Y4.2
GND2: C33.1, C34.1, C35.2, C36.2, C37.2, C38.2, C39.2, C42.2, C43.2, C44.2, C46.1, C47.2, C48.2, D7.C, J25.SLEEVE, J26.P$5, J26.P$6, J27.GND, J27.GND1, J27.GND3, J29.4, J32.1, J34.1, R62.1, R63.1, R64.1, R81.2, R82.2, R83.2, R84.2, R85.2, R86.2, R89.1, R90.1, S3.1, U9.6, U9.8, U9.18, U9.31, U9.38, U9.41, U9.42, U9.48, U10.3, U10.5, U10.21, U11.2, U12.4, Y6.2
GND3: C49.1, C50.1, C51.2, C52.2, C53.2, C54.2, C55.2, C58.2, C59.2, C60.2, C62.1, C63.2, C64.2, D10.C, J37.SLEEVE, J38.P$5, J38.P$6, J39.GND, J39.GND1, J39.GND3, J41.4, J44.1, J46.1, R92.1, R93.1, R94.1, R111.2, R112.2, R113.2, R114.2, R115.2, R116.2, R119.1, R120.1, S4.1, U13.6, U13.8, U13.18, U13.31, U13.38, U13.41, U13.42, U13.48, U14.3, U14.5, U14.21, U15.2, U16.4, Y8.2
GND4: C65.1, C66.1, C67.2, C68.2, C69.2, C70.2, C71.2, C74.2, C75.2, C76.2, C78.1, C79.2, C80.2, D13.C, J49.SLEEVE, J50.P$5, J50.P$6, J51.GND, J51.GND1, J51.GND3, J53.4, J56.1, J58.1, R122.1, R123.1, R124.1, R141.2, R142.2, R143.2, R144.2, R145.2, R146.2, R149.1, R150.1, S5.1, U17.6, U17.8, U17.18, U17.31, U17.38, U17.41, U17.42, U17.48, U18.3, U18.5, U18.21, U19.2, U20.4, Y10.2
GND5: C81.1, C82.1, C83.2, C84.2, C85.2, C86.2, C87.2, C90.2, C91.2, C92.2, C94.1, C95.2, C96.2, D16.C, J61.SLEEVE, J62.P$5, J62.P$6, J63.GND, J63.GND1, J63.GND3, J65.4, J68.1, J70.1, R152.1, R153.1, R154.1, R171.2, R172.2, R173.2, R174.2, R175.2, R176.2, R179.1, R180.1, S6.1, U21.6, U21.8, U21.18, U21.31, U21.38, U21.41, U21.42, U21.48, U22.3, U22.5, U22.21, U23.2, U24.4, Y12.2
GND6: C97.1, C98.1, C99.2, C100.2, C101.2, C102.2, C103.2, C106.2, C107.2, C108.2, C110.1, C111.2, C112.2, D19.C, J73.SLEEVE, J74.P$5, J74.P$6, J75.GND, J75.GND1, J75.GND3, J77.4, J80.1, J82.1, R182.1, R183.1, R184.1, R201.2, R202.2, R203.2, R204.2, R205.2, R206.2, R209.1, R210.1, S7.1, U25.6, U25.8, U25.18, U25.31, U25.38, U25.41, U25.42, U25.48, U26.3, U26.5, U26.21, U27.2, U28.4, Y14.2
GND7: C113.1, C114.1, C115.2, C116.2, C117.2, C118.2, C119.2, C122.2, C123.2, C124.2, C126.1, C127.2, C128.2, D22.C, J85.SLEEVE, J86.P$5, J86.P$6, J87.GND, J87.GND1, J87.GND3, J89.4, J92.1, J94.1, R212.1, R213.1, R214.1, R231.2, R232.2, R233.2, R234.2, R235.2, R236.2, R239.1, R240.1, S8.1, U29.6, U29.8, U29.18, U29.31, U29.38, U29.41, U29.42, U29.48, U30.3, U30.5, U30.21, U31.2, U32.4, Y16.2
GND8: C129.1, C130.1, C131.2, C132.2, C133.2, C134.2, C135.2, C138.2, C139.2, C140.2, C142.1, C143.2, C144.2, D25.C, J97.SLEEVE, J98.P$5, J98.P$6, J99.GND, J99.GND1, J99.GND3, J101.4, J104.1, J106.1, R242.1, R243.1, R244.1, R261.2, R262.2, R263.2, R264.2, R265.2, R266.2, R269.1, R270.1, S9.1, U33.6, U33.8, U33.18, U33.31, U33.38, U33.41, U33.42, U33.48, U34.3, U34.5, U34.21, U35.2, U36.4, Y18.2
GND9: C145.1, C146.1, C147.2, C148.2, C149.2, C150.2, C151.2, C154.2, C155.2, C156.2, C158.1, C159.2, C160.2, D28.C, J109.SLEEVE, J110.P$5, J110.P$6, J111.GND, J111.GND1, J111.GND3, J113.4, J116.1, J118.1, R272.1, R273.1, R274.1, R291.2, R292.2, R293.2, R294.2, R295.2, R296.2, R299.1, R300.1, S10.1, U37.6, U37.8, U37.18, U37.31, U37.38, U37.41, U37.42, U37.48, U38.3, U38.5, U38.21, U39.2, U40.4, Y20.2
GND10: C161.1, C162.1, C163.2, C164.2, C165.2, C166.2, C167.2, C170.2, C171.2, C172.2, C174.1, C175.2, C176.2, D31.C, J121.SLEEVE, J122.P$5, J122.P$6, J123.GND, J123.GND1, J123.GND3, J125.4, J128.1, J130.1, R302.1, R303.1, R304.1, R321.2, R322.2, R323.2, R324.2, R325.2, R326.2, R329.1, R330.1, S11.1, U41.6, U41.8, U41.18, U41.31, U41.38, U41.41, U41.42, U41.48, U42.3, U42.5, U42.21, U43.2, U44.4, Y22.2
GND11: C177.1, C178.1, C179.2, C180.2, C181.2, C182.2, C183.2, C186.2, C187.2, C188.2, C190.1, C191.2, C192.2, D34.C, J133.SLEEVE, J134.P$5, J134.P$6, J135.GND, J135.GND1, J135.GND3, J137.4, J140.1, J142.1, R332.1, R333.1, R334.1, R351.2, R352.2, R353.2, R354.2, R355.2, R356.2, R359.1, R360.1, S12.1, U45.6, U45.8, U45.18, U45.31, U45.38, U45.41, U45.42, U45.48, U46.3, U46.5, U46.21, U47.2, U48.4, Y24.2
GND12: C193.1, C194.1, C195.2, C196.2, C197.2, C198.2, C199.2, C202.2, C203.2, C204.2, C206.1, C207.2, C208.2, D37.C, J145.SLEEVE, J146.P$5, J146.P$6, J147.GND, J147.GND1, J147.GND3, J149.4, J152.1, J154.1, R362.1, R363.1, R364.1, R381.2, R382.2, R383.2, R384.2, R385.2, R386.2, R389.1, R390.1, S13.1, U49.6, U49.8, U49.18, U49.31, U49.38, U49.41, U49.42, U49.48, U50.3, U50.5, U50.21, U51.2, U52.4, Y26.2
GND13: C209.1, C210.1, C211.2, C212.2, C213.2, C214.2, C215.2, C218.2, C219.2, C220.2, C222.1, C223.2, C224.2, D40.C, J157.SLEEVE, J158.P$5, J158.P$6, J159.GND, J159.GND1, J159.GND3, J161.4, J164.1, J166.1, R392.1, R393.1, R394.1, R411.2, R412.2, R413.2, R414.2, R415.2, R416.2, R419.1, R420.1, S14.1, U53.6, U53.8, U53.18, U53.31, U53.38, U53.41, U53.42, U53.48, U54.3, U54.5, U54.21, U55.2, U56.4, Y28.2
GND14: C225.1, C226.1, C227.2, C228.2, C229.2, C230.2, C231.2, C234.2, C235.2, C236.2, C238.1, C239.2, C240.2, D43.C, J169.SLEEVE, J170.P$5, J170.P$6, J171.GND, J171.GND1, J171.GND3, J173.4, J176.1, J178.1, R422.1, R423.1, R424.1, R441.2, R442.2, R443.2, R444.2, R445.2, R446.2, R449.1, R450.1, S15.1, U57.6, U57.8, U57.18, U57.31, U57.38, U57.41, U57.42, U57.48, U58.3, U58.5, U58.21, U59.2, U60.4, Y30.2
GND15: C241.1, C242.1, C243.2, C244.2, C245.2, C246.2, C247.2, C250.2, C251.2, C252.2, C254.1, C255.2, C256.2, D46.C, J181.SLEEVE, J182.P$5, J182.P$6, J183.GND, J183.GND1, J183.GND3, J185.4, J188.1, J190.1, R452.1, R453.1, R454.1, R471.2, R472.2, R473.2, R474.2, R475.2, R476.2, R479.1, R480.1, S16.1, U61.6, U61.8, U61.18, U61.31, U61.38, U61.41, U61.42, U61.48, U62.3, U62.5, U62.21, U63.2, U64.4, Y32.2
IO_0: R12.1, U1.32, U2.2
IO_1: R28.1, U1.1, U2.3
IO_2: R29.1, U1.2, U2.4
IO_3: R30.1, U1.9, U2.5
IO_4: R31.1, U1.10, U2.9
IO_5: R52.1, U5.2, U6.32
IO_6: R11.1, U2.11
IO_7: R22.1, U2.12
IO_8: R53.1, U5.3, U6.1
IO_9: R54.1, U5.4, U6.2
IO_10: R55.1, U5.5, U6.9
IO_11: R56.1, U5.9, U6.10
IO_12: R51.1, U5.11
IO_13: R43.1, U5.12
IO_14: R82.1, U9.2, U10.32
IO_15: R83.1, U9.3, U10.1
IO_16: R84.1, U9.4, U10.2
IO_17: R85.1, U9.5, U10.9
IO_18: R86.1, U9.9, U10.10
IO_19: R81.1, U9.11
IO_20: R73.1, U9.12
IO_21: R112.1, U13.2, U14.32
IO_22: R113.1, U13.3, U14.1
IO_23: R114.1, U13.4, U14.2
IO_24: R115.1, U13.5, U14.9
IO_25: R116.1, U13.9, U14.10
IO_26: R111.1, U13.11
IO_27: R103.1, U13.12
IO_28: R142.1, U17.2, U18.32
IO_29: R143.1, U17.3, U18.1
IO_30: R144.1, U17.4, U18.2
IO_31: R145.1, U17.5, U18.9
IO_32: R146.1, U17.9, U18.10
IO_33: R141.1, U17.11
IO_34: R133.1, U17.12
IO_35: R172.1, U21.2, U22.32
IO_36: R173.1, U21.3, U22.1
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

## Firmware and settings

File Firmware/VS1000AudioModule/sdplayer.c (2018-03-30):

 /*
  Copyright 2008-2013 VLSI Solution Oy. Absolutely no warranty.
*/
#include <stdio.h>
#include <stdlib.h>
#include <string.h>
#include <vs1000.h>
#include <audio.h>
#include <mappertiny.h>
#include <minifat.h>
#include <codec.h>
#include <vsNand.h>
#include <player.h>
#include <usblowlib.h>

#include "system.h"

//#define TEST_WRITE /* modifies config.txt */


#ifdef UART_CONTROL
#include "uartctrl.h"
#endif/*UART_CONTROL*/
#ifdef GPIO_CONTROL
#include "gpioctrl.h"
#endif /*GPIO_CONTROL*/

#ifdef USE_QUEUE
#define QUEUE_SIZE 100
s_int16 queued = 0;
u_int16 queue[QUEUE_SIZE];
#endif/*USE_QUEUE*/

#define USE_USB /* You get a bit more free code space if you disable USB. */
#ifdef DISABLE_USB
#undef USE_USB
#endif

//#undef USE_WAV
//#define USE_DEBUG
//#define DEBUG_LEVEL 3

#define USE_HC      /* Support SD-HC cards. */

// The VLSI RDY LED on the PAPA soundie is GPIO pin 5
#define VLSI_RDY_LED (32)


#include <dev1000.h>

/*
  TODO: use multiple block read and multiple block write
  TODO: readahead using multiple block read?
  TODO: multiple block write would need error handling, possibly rewrites

  Start Block Tokens and Stop Tran Token:
  Single block read, single block write, multiple block read:
  - start block 0xfe
  Multiple block write (CMD25):
  - start block 0xfc
  - stop transmission 0xfd

  Multiple block read (CMD18):
  - stop transmission: STOP_TRAN = CMD12

  state transitions:
  ok -> read>ok
  ok -> (0xfe)write>ok
  ok -> (0xfe)write>writewait -> ok

  state transitions:
  ok -> readm(0xfe) -> readm(0xfe) -(STOP_TRAN)-> ok
  ok -> (0xfc)writem ->writemw -> (0xfc)writem -> writemw -(0xfd)-> ok

 */


enum mmcState {
    mmcNA = 0,
    mmcOk = 1,
    mmcWriteWait = 2, /* waiting for write to finish */
};
struct {
    enum mmcState state;
    s_int16 errors;
    s_int16 hcShift;
    u_int32 blocks;
#ifdef USE_MULTIPLE_BLOCK_WRITE
    u_int32 nextWriteBlock;
#endif
} mmc;


#ifdef USE_DEBUG
static char hex[] = "0123456789ABCDEF";
void puthex(u_int16 d) {
    register int i;
    char mem[5];
    for (i=0;i<4;i++) {
        mem[i] = hex[(d>>12)&15];
        d <<= 4;
    }
    mem[4] = '\0';
    fputs(mem, stdout);
}
#endif


extern struct FsNandPhys fsNandPhys;
extern struct FsPhysical *ph;
extern struct FsMapper *map;
extern struct Codec *cod;
extern struct CodecServices cs;
//extern u_int16 codecVorbis[];


s_int16 InitializeMmc(s_int16 tries) {
    register s_int16 i, cmd;
    mmc.state = mmcNA;
    mmc.blocks = 0;
    mmc.errors = 0;
#ifdef USE_MULTIPLE_BLOCK_WRITE
    mmc.nextWriteBlock = 0xffffffff;
#endif

#if DEBUG_LEVEL > 1
    puthex(clockX);
    puts(" clockX");
#endif
 tryagain:
    IdleHook();

    mmc.hcShift = 9;
    if (tries-- <= 0) {
        return ++mmc.errors;
    }
    for (i=0; i<512; i++) {
        SpiSendClocks();
    }

    /* MMC Init, command 0x40 should return 0x01 if all is ok. */
    i = MmcCommand(MMC_GO_IDLE_STATE/*CMD0*/|0x40,0);
    if (i != 1) {
#if DEBUG_LEVEL > 1
        puthex(i);
        puts(" Init");
#endif
        BusyWait10();
        goto tryagain;//continue; /* No valid idle response */
    }
    cmd = MMC_SEND_OP_COND|0x40;
#ifdef USE_HC
    /*CMD8 is mandatory before ACMD41 for hosts compliant to phys. spec. 2.00*/
    i = MmcCommand(MMC_SEND_IF_COND/*CMD8*/|0x40,
                   0x00000122/*2.7-3.6V*/); /*note: 0x22 for the right CRC!*/
#if DEBUG_LEVEL > 2
    puthex(i);
    puts("=IF_COND");
#endif
    if (i == 1) {
        /* MMC answers: 0x05 illegal command, v2.0 SD(HC-SD) answers: 0x01 */
        /* Should we read the whole R7 response? */
#if DEBUG_LEVEL > 1
        //SpiSendReceiveMmc(-1, 32);
        puthex(SpiSendReceiveMmc(-1, 16));
        puthex(SpiSendReceiveMmc(-1, 16));
        puts("=R7");
#else
        SpiSendReceiveMmc(-1, 32); /*read the whole response*/
#endif
        cmd = 0x40|41; /* ACMD41 - SD_SEND_OP_COND */
    }
#endif /*USE_HC*/


#if 0
    do {
        i = MmcCommand(MMC_READ_OCR/*CMD58*/|0x40, 0);
#if DEBUG_LEVEL > 1
        puthex(i);
        puthex(SpiSendReceiveMmc(-1, 16));
        puthex(SpiSendReceiveMmc(-1, 16));
        puts("=READ_OCR");
#endif
    } while (0);
#else
    /* Some cards require CMD58 after CMD8 -- does this still work with MMC?*/
    MmcCommand(MMC_READ_OCR/*CMD58*/|0x40, 0);
    SpiSendReceiveMmc(-1, 16);
    SpiSendReceiveMmc(-1, 16);
#endif

    /* MMC Wake-up call, set to Not Idle (mmc returns 0x00)*/
    i = 0; /* i is 1 when entered .. but does not make the code shorter*/
    while (1) {
        register int c;
#ifdef USE_HC
        if (cmd == (0x40|41)) {
            c = MmcCommand(0x40|55/*CMD55*/,0);
#if DEBUG_LEVEL > 2
            puthex(c);
            puts("=CMD55");
#endif
        }
#endif

        c = MmcCommand(cmd/*MMC_SEND_OP_COND|0x40*/,
#ifdef USE_HC
                       /* Support HC for SD, AND for MMC! */
                       //i ? 0x40100000UL : 0x00000000UL
                       0x40100000UL
#else
                       0
#endif
            );

#if DEBUG_LEVEL > 1
        puthex(c);
        puts("=ACMD41");
#endif

        if (c == 0) {
#if DEBUG_LEVEL > 1
            puts("got 0");
#endif
            break;
        }
        //BusyWait10();
        if (++i >= 25000 /*Large value (12000) required for MicroSD*/
            || c != 1) {
#if DEBUG_LEVEL > 1
            puthex(c);
            puts(" Timeout 2");
#endif
            goto tryagain; /* Not able to power up mmc */
        }
    }
#ifdef USE_HC
    i = MmcCommand(MMC_READ_OCR/*CMD58*/|0x40, 0);
#if DEBUG_LEVEL > 1
    puthex(i);
    puts("=READ_OCR");
#endif
    if (//cmd == (0x40|41) &&
        i == 0) {
        if (SpiSendReceiveMmc(-1, 16) & (1<<(30-16))) {
            /* OCR[30]:CCS - card capacity select */
            /* HighCapacity! */
#if DEBUG_LEVEL > 1
            puts("=HC");
#endif
            mmc.hcShift = 0;
        }
        /*read all of the OCR data to make some cards happy */
        SpiSendReceiveMmc(-1, 16);
    }
#endif /*USE_HC*/

#if DEBUG_LEVEL > 4
    if (MmcCommand(MMC_SEND_CID/*CMD10*/|0x40, 0) == 0) {
        register s_int16 *p = minifatBuffer;
        register int t = 3200;
        while (SpiSendReceiveMmc(0xff00, 8) == 0xff) {
            if (t-- == 0)
                goto tryagain;
        }
        for (i=0; i<8; i++) {
            *p++ = SpiSendReceiveMmc(-1, 16);
#if DEBUG_LEVEL > 1
            puthex(p[-1]);
#endif
/*
       Man     Productname   serial#   date
          App             rev        res    crc7+stop
  4G:  1D 4144 0000000000 00 0000157A 0 06A E3
  64M: 02 0000 53444D3036 34 40185439 0 C77 75
       00 0011 1122223333 44 44555566 6 677 77
*/
        }
#if DEBUG_LEVEL > 1
        puts("=CID");
#endif
    }
#endif

#if 0
    /* Set Block Size of 512 bytes -- default for at least HC */
    /* Needed by MaxNova S043618ATA 2J310700 MV016Q-MMC */
    /* Must check return value! (MicroSD restart!) */
    {
        register int c;
        if ((c = MmcCommand(MMC_SET_BLOCKLEN|0x40, 512)) != 0) {
#if DEBUG_LEVEL > 1
            puthex(c);
            puts(" SetBlockLen failed");
#endif
            goto tryagain;
        }
    }
#endif
    /* All OK return */
    //mmc.errors = 0;
    mmc.state = mmcOk;
    return 0;//mmc.errors;
}

struct FsMapper *FsMapMmcCreate(struct FsPhysical *physical,
                                u_int16 cacheSize);
u_int16 FsMapMmcRead(struct FsMapper *map, u_int32 firstBlock,
                     u_int16 blocks, u_int16 *data);
u_int16 FsMapMmcWrite(struct FsMapper *map, u_int32 firstBlock,
                      u_int16 blocks, u_int16 *data);

auto u_int16 MyReadDiskSector(register __i0 u_int16 *buffer,
                              register __reg_a u_int32 sector) {
    register s_int16 i;
    register u_int16 t = 65535;

    if (mmc.state == mmcNA || mmc.errors) {
        cs.cancel = 1;
        return 5;
    }
#ifdef USE_MULTIPLE_BLOCK_WRITE
    /* with "if" it is a little faster, but more code */
    //if (mmc.nextWriteBlock != 0xffffffff)
    {
        /* Finalize write mode */
        FsMapMmcWrite(NULL, 0, 0, NULL);
    }
#endif

#if 0 && defined(USE_DEBUG)
    puthex(sector>>16);
    puthex(sector);
    puts("=ReadDiskSector");
#endif
#ifdef USE_HC
    MmcCommand(MMC_READ_SINGLE_BLOCK|0x40,(sector<<mmc.hcShift));
#else
    MmcCommand(MMC_READ_SINGLE_BLOCK|0x40,(sector<<9));
#endif
    do {
        i = SpiSendReceiveMmc(0xff00,8);
    } while (i == 0xff && --t != 0);

    if (i != 0xfe) {
        memset(buffer, 0, 256);
        if (i > 15 /*unknown error code*/) {
            mmc.errors++;
        } else {
            /* data retrieval failed:
               D4-D7 = 0
               D3 = out of range
               D2 = Card ECC Failed
               D1 = CC Error
               D0 = Error
             */
        }
        SpiSendClocks();
        return 1;
    }
    for (i=0; i<512/2; i++) {
        *buffer++ = SpiSendReceiveMmc(0xffff,16);
#if 0
        puthex(buffer[-1]);
        if ((i & 15) == 15)
            puts("");
#endif
    }
    SpiSendReceiveMmc(0xffff,16); /* discard crc */

    /* generate some extra SPI clock edges to finish up the command */
    SpiSendClocks();
    SpiSendClocks();

    /* We force a call of user interface after each block even if we
       have no idle CPU. This prevents problems with key response in
       fast play mode. */
    IdleHook();
    return 0; /* All OK return */
}

#ifdef USE_MULTIPLE_BLOCK_WRITE
s_int16 FsMapMmcFlush(struct FsMapper *map, u_int16 hard) {
    /* Finalize write mode */
    FsMapMmcWrite(NULL, 0, 0, NULL);
    return 0;
}
#endif

#if 0
struct FsMapper *FsMapMmcCreate(struct FsPhysical *physical,
                                u_int16 cacheSize) {
    PERIP(GPIO0_MODE) &= ~(MMC_MISO|MMC_CLK|MMC_MOSI|MMC_XCS);
    PERIP(GPIO0_DDR) = (PERIP(GPIO0_DDR) & ~(MMC_MISO))
        | (MMC_CLK|MMC_MOSI|MMC_XCS)
        | GPIO0_SD_POWER;
    PERIP(GPIO0_ODATA) = (PERIP(GPIO0_ODATA) & ~(MMC_CLK|MMC_MOSI))
        | (MMC_XCS | GPIO0_CS1); /* NFCE high */
#if DEBUG_LEVEL > 1
    puts("Configured MMC pins\n");
#endif
    memset(&mmc, 0, sizeof(mmc));
    return &mmcMapper;
}
#endif




void CheckSd(void) {
#if 0
    if ((PERIP(GPIO0_IDATA) & (1<<14))) {
        /* SD not inserted */
        putstrp("\p!SD\n");

        /* If SD is not inserted, run SPI FLASH player. */
        //SetHookFunction((u_int16)ReadDiskSector, MapperReadDiskSector);
        PERIP(SPI0_CONFIG) = SPI_CF_MASTER | SPI_CF_DLEN8 | SPI_CF_FSIDLE1;
        ResetIRAMVectors();
        SpiLoad(SPIPLAYERSTART+4, 1/*24-bit address*/);
    }
#endif
}
#ifdef TEST_WRITE
u_int32 dirSector;
u_int16 *dirEntry = NULL, *dirName = NULL;
#endif
void IterateFilesCallback(register __b0 u_int16 *name) {
    register int i;
#ifdef TEST_WRITE
    /* If dirName is not NULL,
       capture some data required to update the file entry.
       Otherwise perform the normal operation.
     */
    if (dirName) {
        if (!memcmp(dirName, name, 4)) { /* 8 characters match */
            dirSector = minifatInfo.currentSector;
            dirEntry = name; /*points to minifatBuffer*/
        }
        return;
    }
#endif /*TEST_WRITE*/

    /* Dump the whole FAT directory entry */
    for (i=0;i<32/2;i++) {
        putword(*name++);
    }
#ifdef SHOW_LONG_FILENAMES
    if (minifatInfo.longFileName[0]) {
        register __y s_int16 *p = minifatInfo.longFileName;
        while (*p >> 8) {
            putch(*p >> 8);
            if (*p & 255) {
                putch(*p & 255);
            } else {
                break;
            }
            p++;
        }
    }
    putch('\n');
#endif
}

#ifdef TEST_WRITE
/* This is a slightly edited version from sdmass.c -
   some features have been removed. */
u_int16 FsMapMmcWrite(struct FsMapper *map, u_int32 firstBlock,
                      u_int16 blocks, u_int16 *data) {
    /* We know this is called one block at a time by the USB ROM firmware,
       or our own code, so only prepare for that and save 14 words. */
    {
        register u_int16 c;
        if (mmc.state == mmcNA || mmc.errors)
            return 0;
#ifdef USE_HC
        c = MmcCommand(MMC_WRITE_BLOCK|0x40, firstBlock<<mmc.hcShift);
#else
        c = MmcCommand(MMC_WRITE_BLOCK|0x40, firstBlock<<9);
#endif
        //wait for BUSY token, if you get 0x01(idle), it's an ERROR!
        while (c != 0x00) {
            if (c == 0x01) {
                mmc.errors++;
                goto out;
            }
            c = SpiSendReceiveMmc(0xff00, 8);
            /*TODO: timeout?*/
        }
        SpiSendReceiveMmc(0xfffe, 16);
        for (c=0; c<256; c++) {
            SpiSendReceiveMmc(*data++, 16);
        }
        SpiSendReceiveMmc(0xffff, 16); /* send dummy CRC */
        /* wait until MMC write finished */
        do {
            /*TODO: timeout?*/
        } while ( SpiSendReceiveMmc(0xff00U, 8) != 0x00ffU);
    }
 out:
    SpiSendClocks();
    return 1;
}

static s_int16 fatBufDirty = 0; /* non-zero if minifatBuffer has been modified */

auto u_int16 FatOpenFileWrite(u_int16 *name, u_int32 suffix) {
    u_int32 ext[2];
    ext[0] = suffix;
    ext[1] = 0;
    minifatInfo.supportedSuffixes = ext;
    dirName = name;
    dirEntry = 0;
    IterateFiles();
    /* Clear dirName, so that IterateFiles works normally again.*/
    dirName = NULL;
    /* Restore the default suffixes. */
    minifatInfo.supportedSuffixes = supportedFiles;

    if (!dirEntry) {
        /* The entry was not found. */
        return 0;
    }
    /* Open to get the fragments and other data correct.
       We already know that it should exist.*/
    return OpenFileNamed(name, suffix) != 0xffffU;
}


/* Analogous to FatReadFile. The data is packed bytes, byteOff can be used
   to start at any byte inside the word array. */
auto s_int16 FatWriteFile(register __i3 u_int16 *buf,
        		  register __c1 s_int16 byteOff,
        		  register __c0 s_int16 byteSize) {
    __mem_y s_int16 srcIdx = byteOff;
    s_int16 writeAmount;
    while (byteSize) {
        writeAmount = byteSize;
        /* Check for sector boundary. Split into two writes if needed. */
        if ((minifatInfo.filePos >> 9) <
            ((minifatInfo.filePos + writeAmount - 1) >> 9)) {
            writeAmount = 512 - ((u_int16)minifatInfo.filePos & 511);
        }
        /* Prevent writing off the end of the allocated space of a file.
           This requires that the file size will be fixed in FatCloseFile.
        */
        if (minifatInfo.filePos + writeAmount >
            512*minifatFragments[0].size) {
            writeAmount = minifatFragments[0].size*512-minifatInfo.filePos;
            if (writeAmount <= 0) {
        	return srcIdx - byteOff; /*EOF*/
            }
        }

        {
            /*For files shorter than 560MB we don't need PatchFatFindSector()*/
            u_int32 sect = FatFindSector(minifatInfo.filePos);
            if (fatBufDirty) {
        	/*Write a changed sector back to SD before reading over it. */
        	fatBufDirty = 0;
        	FsMapMmcWrite(map, minifatInfo.currentSector, 1,minifatBuffer);
            }
            if (minifatInfo.currentSector != sect) {
        	ReadDiskSector(minifatBuffer, minifatInfo.currentSector= sect);
            }
        }
        MemCopyPackedBigEndian(minifatBuffer,
        		       minifatInfo.filePos & 511,
        		       buf, srcIdx, writeAmount);
        fatBufDirty = 1;
        srcIdx += writeAmount;
        minifatInfo.filePos += writeAmount;
        if (minifatInfo.fileSize < minifatInfo.filePos) {
            minifatInfo.fileSize = minifatInfo.filePos;
        }
        byteSize -= writeAmount;
    }
    return writeAmount;
}
auto s_int16 FatCloseFile(void) {
    if (fatBufDirty) {
        /* Write a modified buffer back to SD*/
        fatBufDirty = 0;
        FsMapMmcWrite(map, minifatInfo.currentSector, 1, minifatBuffer);
    }
    if (dirEntry) {    /* Update file size if possible */
 	ReadDiskSector(minifatBuffer, minifatInfo.currentSector = dirSector);
        /* bytes 28,29,30,31 in the directory entry are the file size
           in little-endian format. */
        dirEntry[28/2] = SwapWord(minifatInfo.fileSize);
        dirEntry[30/2] = SwapWord(minifatInfo.fileSize>>16);
        FsMapMmcWrite(map, minifatInfo.currentSector, 1, minifatBuffer);
    }
    dirEntry = 0; /* We're done with the file */
}
#endif/*TEST_WRITE*/


void main(void) {
#if defined(GPIO_CONTROL) && defined(GPIO_NUMBERED_FILES)
    u_int16 gpNum;
    u_int16 gpName[4] = "\pAUDIO00 ";
#endif
    Enable();

#ifdef GAPLESS
    codecVorbis.audioBegins = 0;
#endif
#if 1
    InitAudio(); /* goto 3.0x..4.0x */
    PERIP(INT_ENABLEL) = INTF_RX | INTF_TIM0;
    PERIP(INT_ENABLEH) = INTF_DAC;
#endif


#ifdef USE_WAV
    /* allow both .WAV and .OGG */
    supportedFiles = defSupportedFiles;
#endif

#if 1
    SetHookFunction((u_int16)OpenFile, FatFastOpenFile); /*Faster+fat12!*/
    //SetHookFunction((u_int16)OpenFile, FatFastOpenFileD); /*Faster!*/
#else
#if !defined(USE_WAV) || !defined(USE_USB)
    /* Ignore subdirectories in FAT12 disks */
    SetHookFunction((u_int16)OpenFile, Fat12OpenFile);
#endif
#endif
    //voltages[voltCorePlayer] = voltages[voltCoreUSB] = 29;//27;
    //voltages[voltIoUSB] = voltages[voltIoPlayer] = 27; /* 3.3V */
    //voltages[voltAnaPlayer] = 30; /*3.6V for high-current MMC/SD!*/
    //PowerSetVoltages(&voltages[voltCorePlayer]);

#ifdef UART_CONTROL
    SetHookFunction((u_int16)IdleHook, NullHook);     /* no default keyscan */
    SetHookFunction((u_int16)USBSuspend, NullHook);   /* no low-power state */
    SetHookFunction((u_int16)LoadCheck, UartLoadCheck); /* fixed clock */
#endif
#ifdef GPIO_CONTROL
  SetHookFunction((u_int16)IdleHook, GPIOCtrlIdleHook);
#endif


    /* Replicate main loop */
//    player.volume = 17;
//    player.volumeOffset = -24;
    player.pauseOn = 0;
    //player.randomOn = 0;
//    keyOld = KEY_POWER;
//    keyOldTime = -32767; /* ignores the first release of KEY_POWER */

    /*
      MMC mapper replaces FLASH mapper, so we do not need to hook
      ReadDiskSector.

      We must also replace the MassStorage() functionality, because it
      automatically deletes mapper, creates a read-write FLASH mapper,
      and restores read-only FLASH mapper at exit.

      We need to replace the main loop because we want to detect
      MMC/SD insertion and removal.

      We do not hook the MassStorage, because we can call our own version
      from the main loop without using the RAM hook. This saves some
      instruction words.
     */
#if 0
    map = FsMapMmcCreate(NULL, 0); /* Create MMC Mapper */
#else
    /* inlined FsMapMmcCreate */
    PERIP(GPIO0_MODE) &= ~(MMC_MISO|MMC_CLK|MMC_MOSI|MMC_XCS);
    PERIP(GPIO0_DDR) = (PERIP(GPIO0_DDR) & ~(MMC_MISO))
        | (MMC_CLK|MMC_MOSI|MMC_XCS)
        | GPIO0_SD_POWER;
    //PERIP(GPIO0_ODATA) = (PERIP(GPIO0_ODATA) & ~(MMC_CLK|MMC_MOSI))
    //| (MMC_XCS | GPIO0_CS1); /* NFCE high */
    PERIP(GPIO0_SET_MASK)   = (MMC_XCS | GPIO0_CS1); /* NFCE high */
    PERIP(GPIO0_CLEAR_MASK) = (MMC_CLK|MMC_MOSI);
    memset(&mmc, 0, sizeof(mmc));
    SetHookFunction((u_int16)ReadDiskSector, MyReadDiskSector);
#endif


//    player.volume = -24; /* "max" volume */
    //PlayerVolume();


#ifdef UART_CONTROL
    UartInit(); //Set interrupt etc.
#endif /*UART_CONTROL*/
#ifdef GPIO_CONTROL
    GPIOInit();
#endif /*GPIO_CONTROL*/

    while (1) {
        CheckSd();

        /* If MMC is not available, try to reinitialize it. */
        if (mmc.state == mmcNA || mmc.errors) {
            /* enable SD power */
            PERIP(GPIO0_SET_MASK) = GPIO0_SD_POWER;
            InitializeMmc(50);
        }

#ifdef USE_USB
        /* If USB is attached, call our version of the MassStorage()
           handling function. */
        if (USBIsAttached()) {
            PERIP(SPI0_CONFIG) = SPI_CF_MASTER | SPI_CF_DLEN8 | SPI_CF_FSIDLE1;
            ResetIRAMVectors();
            if (mmc.state == mmcOk && mmc.errors == 0) {
        	SpiLoad(SDMASSSTART+4, 1/*24-bit address*/);
            } else {
        	SpiLoad(0+4, 1/*24-bit address*/); //spi flash mass-storage
            }
        }
#endif /*USE_USB*/

        /* Try to init FAT. */
        if (InitFileSystem() == 0) {
            /*
              Check if there is an update file (SDUPDATE.PRG) on the SD card.
            */
#ifdef TEST_WRITE
            static int didit = 0;
            if (!didit) {
        	/*
        	   To be able to update the file size, we use
        	   IterateFiles() / IterateFilesCallback() and some internal
        	   structures to locate the file entry to be able to update
        	   it later.

        	   This code with the changes in IterateFilesCallback()
        	   finds the directory sector and entry this file resides
        	   in, so we can optionally fix the file size later. */
        	if (FatOpenFileWrite("\pCONFIG  ", FAT_MKID('T','X','T'))) {

        	    Seek(24); /* skip a bit for testing */
        	    while (FatWriteFile("\palternative \n\r", 0, 14)) {
        		/* Fill the rest of the file with this */
        	    }
        	    FatCloseFile(); /* Flush the last modified sector */

        	    putstrp("\preplaced text in config.txt\n");
        	    putword(minifatInfo.filePos>>16);
        	    putword(minifatInfo.filePos);
        	    putch('\n');
        	}
        	didit = 1; /* do only once */
            }
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

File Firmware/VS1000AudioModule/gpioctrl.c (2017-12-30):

#include "system.h"

#include <stdio.h> //Standard io
#include <stdlib.h> // VS_DSP Standard Library
#include <vs1000.h> // VS1000B register definitions
#include <vectors.h> // VS1000B vectors (interrupts and services)
#include <minifat.h> // Read Only Fat Filesystem
#include <mapper.h> // Logical Disk
#include <string.h> // memcpy etc
#include <player.h> // VS1000B default ROM player
#include <audio.h> // DAC output
#include <codec.h> // CODEC interface
#include <vsNand.h>
#include <mappertiny.h>
#include <usb.h>

#include <dev1000.h>

#include "gpioctrl.h"

extern struct CodecServices cs;

/*
  We currently allow two GPIO controls:
  1) GPIO_MASK for binary-encoded file number, all-zero means idle.
     The playing file is changed when the value changes to another non-zero
     value while a file is playing. The file is repeated if the number
     remains at the GPIO pins after the playback has finished.

     The number of bits used can be configured from 1 to 8 (GPIO0[0:7])
     for 255 files when SD card is used, and from 1 to 13 (GPIO0[0:12])
     for 8191 files when SD card is not used.

  2) GPIO_PRIORITIES for one GPIO per file with priorities.
     Lower number GPIO pin number has priority over a higher number GPIO pin.
     A higher number GPIO pin does not interrupt the playing of a current
     file, even if the lower number GPIO pin is no longer set.
     The file is repeated if a file is selected by the GPIO pins after the
     playback has finished.

     The number of GPIO pins used can be configured from 1 to 8 (GPIO0[0:7])
     when SD card is used, and from 1 to 13 (GPIO0[0:12]) when SD card is
     not used.

  Playing indicator:
     - 
  See system.h for GPIO_NUMBERED_FILES definition
 */

#define GPIO_MASK       0x001f // Sel. file w/ GPIO0 pins in the mask
//#define GPIO_INVERTED   //default state is HIGH, buttons bring low
//#define GPIO_PRIORITIES 0x04ff // Sel. file w/ GPIO0 pins, lower has priority

//#define GPIO0_READY_INDICATOR    GPIO0_CLE
//#define GPIO0_PLAYING_INDICATOR  GPIO0_CLE /*CLE=GPIO0_12*/
/*Note: CLE is a bad choice, because it does not come to an audio module pin.*/
#define GPIO0_PLAYING_INDICATOR  (1<<6) //GPIO0_CLE /*CLE=GPIO0_12*/


#if defined(GPIO_MASK) && defined(GPIO_PRIORITIES)
err 'Both GPIO_MASK and GPIO_PRIORITIES can not be defined at the same time'
#endif



void GPIOCtrlIdleHook(void) {
    if (uiTrigger) {
        uiTrigger = 0;

        /*
          If you want the default firmware key-controls, use KeyScan();
        */

#ifdef GPIO0_PLAYING_INDICATOR
        /* We do it this way so that the logic can be in this file. */
        if (player.currentFile != -1) {
            /* high = playing */
            PERIP(GPIO0_SET_MASK) = GPIO0_PLAYING_INDICATOR;
        } else {
            /* low = waiting for GPIO */
            PERIP(GPIO0_CLEAR_MASK) = GPIO0_PLAYING_INDICATOR;
        }
#endif

  /*TURN GPIO into GPIO mode.*/
#ifdef GPIO_MASK
        /* Direct selection through GPIO pins. */
        {
            register s_int16 mask;
#ifdef GPIO_INVERTED
            /*default state is high, button pulls low to GND */
            PERIP(GPIO0_SET_MASK)   = GPIO_MASK | GPIO0_PULLUPS;
            PERIP(GPIO0_DDR) |= GPIO_MASK;  //Drive to 1
            for (mask = 0;mask<10000;mask++)
        	USEX(0);
            PERIP(GPIO0_DDR) &= ~GPIO_MASK; //To inputs
            for (mask = 0;mask<10000;mask++)
        	USEX(0);
            mask = ((PERIP(GPIO0_IDATA) ^ GPIO0_PULLUPS) & GPIO_MASK) ^ GPIO_MASK;
#else
            /*default state is low, button pulls high to IOVDD*/
            PERIP(GPIO0_CLEAR_MASK) = GPIO_MASK;
            PERIP(GPIO0_SET_MASK)   = GPIO_MASK & GPIO0_PULLUPS;
            PERIP(GPIO0_DDR) |= GPIO_MASK;  //Drive to 0
            for (mask = 0;mask<10000;mask++)
        	USEX(0);
            PERIP(GPIO0_DDR) &= ~GPIO_MASK; //To inputs
            for (mask = 0;mask<10000;mask++)
        	USEX(0);
            mask = (PERIP(GPIO0_IDATA) ^ GPIO0_PULLUPS) & GPIO_MASK;
#endif
//putch(mask);
            if (mask) {
        	if (player.currentFile != mask - 1) {
        	    player.currentFile = player.nextFile = mask - 1;
        	    cs.cancel = 1;
        	    player.pauseOn = 0;
        	}
            }
        }
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

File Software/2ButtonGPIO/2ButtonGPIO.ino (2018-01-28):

/*
 * GPIO PINS: 
 *  
 */

const int GPIO_PLAY01 = 2;
const int GPIO_PLAY02 = 3;
const int GPIO_PLAY03 = 4;
const int GPIO_PLAY04 = 5;
const int GPIO_PLAY05 = 6;
const int GPIO_BUTTON1 = 9;
const int GPIO_BUTTON2 = 10;
const int GPIO_VLSI_POWER_BTN = 7;
const int GPIO_ATMEGA_POWER = A2;


/**
 * Maps a file number to it's binary representation on the GPIO pins e.g. 
 * 5 = 00101, GPIO_PLAY05 = 0, GPIO_PLAY04 = 0, GPIO_PLAY03 = 1, GPIO_PLAY02 = 0, GPIO_PLAY01 = 1
 * 7 = 00111, GPIO_PLAY05 = 0, GPIO_PLAY04 = 0, GPIO_PLAY03 = 1, GPIO_PLAY02 = 1, GPIO_PLAY01 = 1
 * 23 = 10111 GPIO_PLAY05 = 1, GPIO_PLAY04 = 0, GPIO_PLAY03 = 1, GPIO_PLAY02 = 1, GPIO_PLAY01 = 1
 */
void playFileNumber(int number) {
  digitalWrite(GPIO_PLAY01, number & 0x01);  
  digitalWrite(GPIO_PLAY02, number & 0x02);
  digitalWrite(GPIO_PLAY03, number & 0x04);
  digitalWrite(GPIO_PLAY04, number & 0x08);
  digitalWrite(GPIO_PLAY05, number & 0x10);
}

/**
 * Sets the required GPIO pins as output
 */
void setupGPIOPins() {
  pinMode(GPIO_PLAY01, OUTPUT);
  pinMode(GPIO_PLAY02, OUTPUT);
  pinMode(GPIO_PLAY03, OUTPUT);
  pinMode(GPIO_PLAY04, OUTPUT);
  pinMode(GPIO_PLAY05, OUTPUT);
}

void setup() {
  pinMode(GPIO_BUTTON1, INPUT);
  pinMode(GPIO_BUTTON2, INPUT);
  pinMode(GPIO_VLSI_POWER_BTN, OUTPUT);
  pinMode(GPIO_VLSI_POWER_BTN, OUTPUT);
  pinMode(GPIO_ATMEGA_POWER, OUTPUT);

  digitalWrite(GPIO_VLSI_POWER_BTN, 0);
  digitalWrite(GPIO_VLSI_POWER_BTN, 1);
  delay(50);
  digitalWrite(GPIO_VLSI_POWER_BTN, 0);
  digitalWrite(GPIO_ATMEGA_POWER, 1);
  setupGPIOPins();
}

// the loop function runs over and over again forever
void loop() {
  
  int button1 = digitalRead(GPIO_BUTTON1);
  int button2 = digitalRead(GPIO_BUTTON2);
  playFileNumber(button2 << 1 | button1);
}

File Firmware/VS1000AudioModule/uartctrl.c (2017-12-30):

#include "system.h"

#include <stdio.h> //Standard io
#include <stdlib.h> // VS_DSP Standard Library
#include <vs1000.h> // VS1000B register definitions
#include <vectors.h> // VS1000B vectors (interrupts and services)
#include <minifat.h> // Read Only Fat Filesystem
#include <mapper.h> // Logical Disk
#include <string.h> // memcpy etc
#include <player.h> // VS1000B default ROM player
#include <audio.h> // DAC output
#include <codec.h> // CODEC interface
#include <vsNand.h>
#include <mappertiny.h>
#include <usb.h>

#include <dev1000.h>

#include "uartctrl.h"
#include "system.h"

/* Note: this file does not check the UART_CONTROL define */

/* lower volume during song cancel, which is especially useful when
   changing songs from pause mode (waiting samples from the current
   song are not heard).
   Note: the QUIET_CANCEL define must be enabled in sdplayer.c and
         spiplayer.c (or system.h) as well.
 */
//#define QUIET_CANCEL

extern struct CodecServices cs;


/* Our own loadcheck which will use fixed 3.0x clock for player
   and 4.0x for USB. But as we don't have USB mode in this program,
   we would only need fixed clock. */
void UartLoadCheck(struct CodecServices *cs, s_int16 n) {
  if (cs == NULL) {
#if 1 /* USB is not serviced in spiplayer, but is in sdplayer. */
    if (n) {
        clockX = 8; /* USB requires 4.0x! */
        goto set;
    }
#endif
#ifdef GAPLESS
    if (clockX != 7) {
        clockX = 7; /* Otherwise 3.5x */
    set:
        SetRate(hwSampleRate);
    }
#else
    if (clockX != 6) {
        clockX = 6; /* Otherwise 3.0x */
    set:
        SetRate(hwSampleRate);
    }
#endif
    return;
  }
  /* cs is always non-NULL here */
  if (cs->gain != player.volumeOffset) {
    player.volumeOffset = cs->gain; /* vorbis-gain */
    PlayerVolume();
  }
}

#ifdef USE_QUEUE
extern s_int16 queued;
#endif

/*
  Only used during file play.
 */
void UartIdleHook(void) {
/*
  Controls:
 */
    if (UartFill()) {
        register int cmd = UartGetByte();
        if (cmd == 'f') {
            /* file mode */
            playerMode = PLAYER_WAIT_FOR_COMMAND;
        } else if (cmd == 'c') {
            /* continuous play mode */
            playerMode = PLAYER_CONTINUOUS_PLAY;
        } else if (cmd == 'C') {
            putch('c');
            goto cancelpauseoff;
            //cs.cancel = 1;
            //player.pauseOn = 0;
        } else if (cmd == '+') {
            KeyEventHandler(ke_volumeUp2);
            goto showvol;//putword(player.volume);
        } else if (cmd == '-') {
            KeyEventHandler(ke_volumeDown2);
        showvol:
            putword(player.volume);
        } else if (cmd == '=') {
            /* pause */
            player.pauseOn = 1;
            goto echo;//putch('=');
        } else if (cmd == '>') {
            /* play */
            player.pauseOn = 0;
            cs.fastForward = 1;
            goto echo;//putch('>');
        } else if (cmd == '»') {
            /* Fast forward */
            //if (cs.fastForward < 4)
        	++cs.fastForward;
            putch(cs.fastForward);
        } else if (cmd == 'n') {
            /* next */
            player.nextFile = player.currentFile + 1;
            putch('n');
            goto cancelpauseoff;
            //cs.cancel = 1;
            //player.pauseOn = 0;
        } else if (cmd == 'p') {
            /* previous */
            player.nextFile = player.currentFile - 1;
            putch('p');
            goto cancelpauseoff;
            //cs.cancel = 1;
            //player.pauseOn = 0;
        } else if (cmd == '?') {
            /* position + other info -- Note: will block. */
            putword(cs.playTimeSeconds>>16);
            putword(cs.playTimeSeconds);
            putch(cs.fileLeft / ((cs.fileSize >> 8)+1));
#ifdef USE_QUEUE
        } else if (cmd == 'R') {
            queued = 0;
            putch('R');
            goto cancelpauseoff;
#endif
        } else {
            /*unknown command*/
        echo:
            putch(cmd);
        }
    }

    if (uiTrigger) {
        uiTrigger = 0;
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

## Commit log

2017-11-13 trying something new
    [Papa_Soundie_doublesided.brd, Papa_Soundie_doublesided.sch]
2017-11-14 final layout
    [Papa_Soundie.brd, Papa_Soundie.sch, Papa_Soundie_doublesided.brd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]
2017-11-14 added pull-up resistor on XCS line
    [Papa_Soundie.brd, Papa_Soundie.sch]
2017-12-05 added measurement to third standoff
    [Papa_Soundie.brd, Papa_Soundie.sch]
2017-12-06 changes per QC Review
    [Papa_Soundie.brd, Papa_Soundie.sch]
2017-12-06 Fixing issues per QC review
    [Papa_Soundie.brd]
2017-12-30 Add 2 Button GPIO example
2018-01-04 Updated design for rev 2
    [Papa_Soundie.brd, Papa_Soundie.sch]
2018-01-11 Updated Version No., removed ground connection from SD Card, v03
    [Papa_Soundie.brd, Papa_Soundie.sch]
2018-01-28 Add Power control and LED status
    - Control VS1000 with arduino GPIO pin pulse
    - Turn on Arduino status LED
2018-01-28 Add VS1000 status LED
2018-02-12 fixing enable line, SD3V3
    [Papa_Soundie.brd, Papa_Soundie.sch]
2018-02-13 updated version no V10
    [Papa_Soundie.brd, Papa_Soundie.sch]
2018-02-13 updating silk, cleaning sch
    [Papa_Soundie.brd, Papa_Soundie.sch]
2018-02-13 fixed DRC issues
    [Papa_Soundie.brd]
2018-02-26 created panel v10
    [Papa_Soundie-Panel_v10.brd]
2018-03-16 converting Arduino Sketch to Library
2018-07-26 Updated input voltage range
    [Papa_Soundie.sch]

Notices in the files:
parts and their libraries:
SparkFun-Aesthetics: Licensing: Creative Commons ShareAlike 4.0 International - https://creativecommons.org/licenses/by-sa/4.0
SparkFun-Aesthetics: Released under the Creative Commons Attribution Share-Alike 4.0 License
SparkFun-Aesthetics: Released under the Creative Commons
